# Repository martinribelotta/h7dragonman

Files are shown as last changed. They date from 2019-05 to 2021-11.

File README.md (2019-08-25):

# H7-DragonMAN board

STM32H7 LQFP100 board for protocol bridge and industrial control.

## Characterstics:

 - Isolated (see `isolated` branch) and non isolated version
 - STM32H750/743VxTx400MHz in 100LQFP with 8MHz/32.768Khz crystals and ROM Bootloader via USB
 - STM32-based DAP programmer and virtual usb with ROM bootloader via USB
 - External 2/4/8/16MB QSPI flash
 - MicroSD card 1bit slot
 - Two usb otg (FS and HS)
 - 10/100Mb ETH via KSZ8081 in RMII mode
 - RS485 isolated or non-isolated
 - CANBUS isolated or non-isolated
 - Isolated 3.3 to 5V step-up for CANBUS/RS-485 tranceivers
 - One user button
 - One user led
 - 5-24V input via AP63203 DC-DC regulator

## Schematic

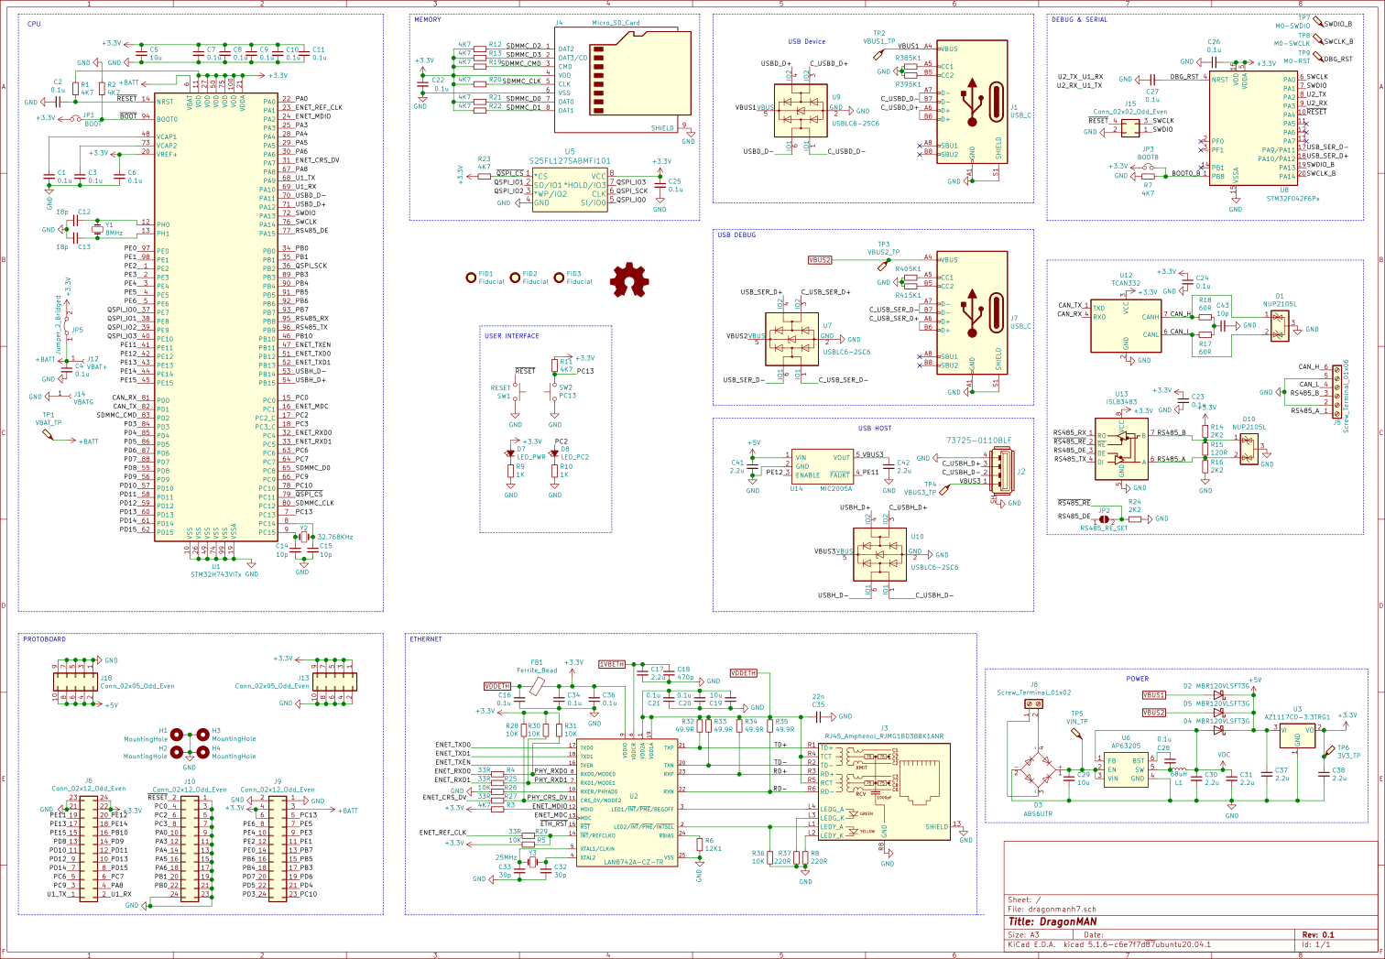
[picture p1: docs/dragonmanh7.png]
Schematic


## Board dimentions

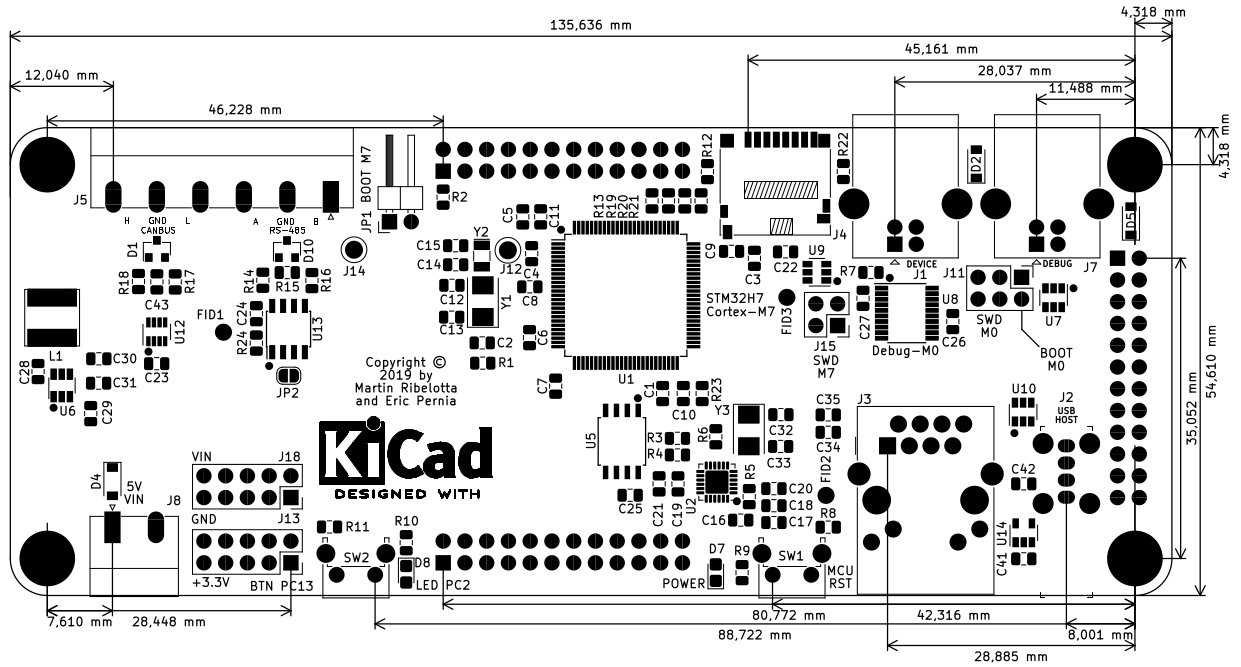
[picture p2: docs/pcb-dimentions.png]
Outline


## 3D preview

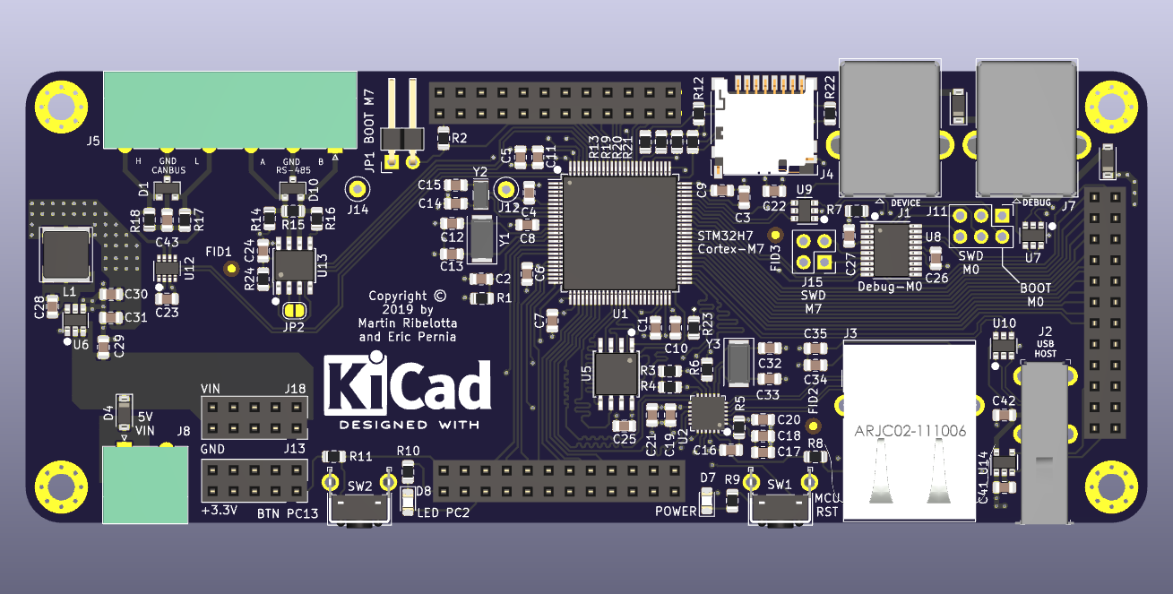
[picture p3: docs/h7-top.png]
top


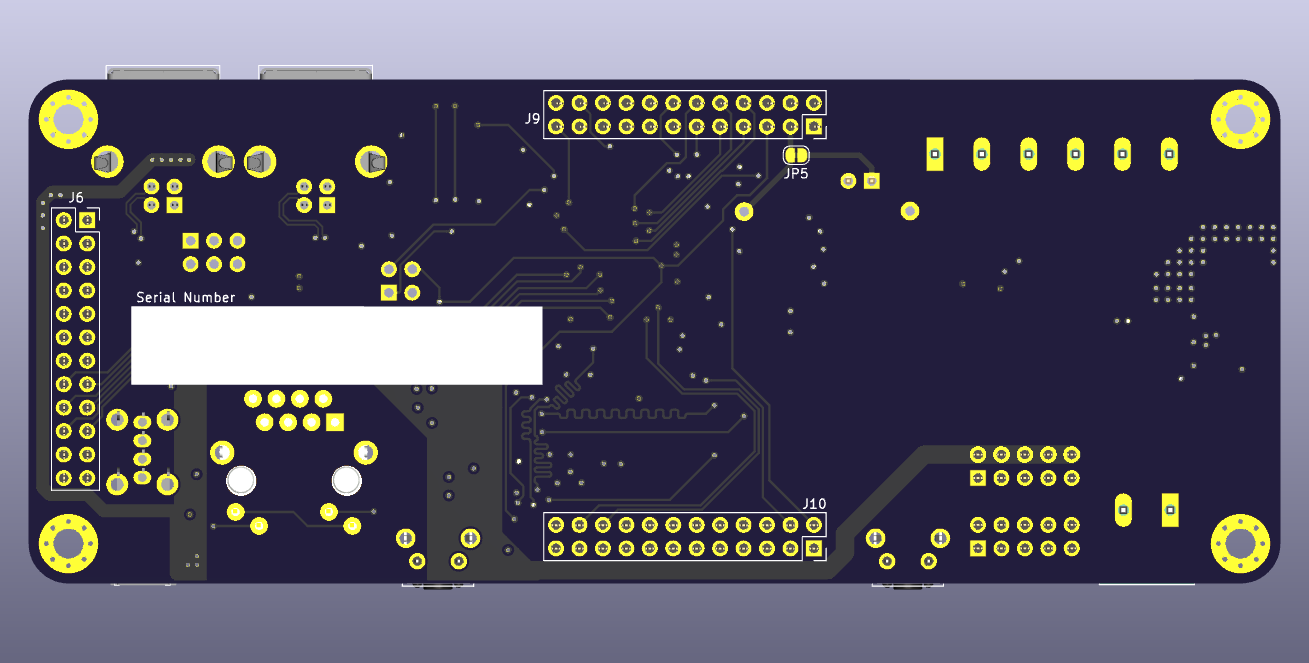
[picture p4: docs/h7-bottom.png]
bottom


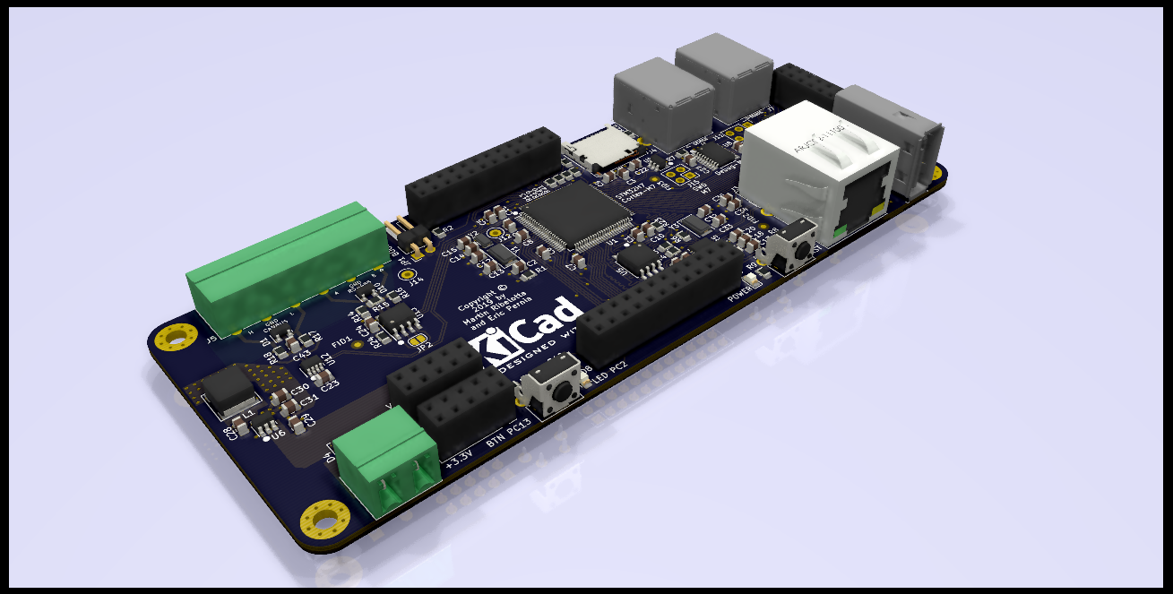
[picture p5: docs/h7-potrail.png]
potrail


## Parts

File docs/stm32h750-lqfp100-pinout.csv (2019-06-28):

Position | Name | Type | Signal | Label | AF0 | AF1 | AF2 | AF3 | AF4 | AF5 | AF6 | AF7 | AF8 | AF9 | AF10 | AF11 | AF12 | AF13 | AF14
1 | PE2 | I/O |  |  | SYS_TRACECLK |  | SAI1_CK1 |  |  | SPI4_SCK | SAI1_MCLK_A |  | SAI4_MCLK_A | QUADSPI_BK1_IO2 | SAI4_CK1 | ETH_TXD3 | FMC_A23
2 | PE3 | I/O |  |  | SYS_TRACED0 |  |  |  | TIM15_BKIN |  | SAI1_SD_B |  | SAI4_SD_B |  |  |  | FMC_A19
3 | PE4 | I/O |  |  | SYS_TRACED1 |  | SAI1_D2 | DFSDM1_DATIN3 | TIM15_CH1N | SPI4_NSS | SAI1_FS_A |  | SAI4_FS_A |  | SAI4_D2 |  | FMC_A20 | DCMI_D4 | LTDC_B0
4 | PE5 | I/O |  |  | SYS_TRACED2 |  | SAI1_CK2 | DFSDM1_CKIN3 | TIM15_CH1 | SPI4_MISO | SAI1_SCK_A |  | SAI4_SCK_A |  | SAI4_CK2 |  | FMC_A21 | DCMI_D6 | LTDC_G0
5 | PE6 | I/O |  |  | SYS_TRACED3 | TIM1_BKIN2 | SAI1_D1 |  | TIM15_CH2 | SPI4_MOSI | SAI1_SD_A |  | SAI4_SD_A | SAI4_D1 | SAI2_MCLK_B | TIM1_BKIN2_COMP1/TIM1_BKIN2_COMP2 | FMC_A22 | DCMI_D7 | LTDC_G1
6 | VBAT | Power
7 | PC13 | I/O
8 | PC14-OSC32_IN (OSC32_IN) | I/O
9 | PC15-OSC32_OUT (OSC32_OUT) | I/O
10 | VSS | Power
11 | VDD | Power
12 | PH0-OSC_IN (PH0) | I/O
13 | PH1-OSC_OUT (PH1) | I/O
14 | NRST | Reset
15 | PC0 | I/O |  |  |  |  |  | DFSDM1_CKIN0 |  |  | DFSDM1_DATIN4 |  | SAI2_FS_B |  | USB_OTG_HS_ULPI_STP |  | FMC_SDNWE |  | LTDC_R5
16 | PC1 | I/O |  |  | SYS_TRACED0 |  | SAI1_D1 | DFSDM1_DATIN0 | DFSDM1_CKIN4 | I2S2_SDO/SPI2_MOSI | SAI1_SD_A |  | SAI4_SD_A | SDMMC2_CK | SAI4_D1 | ETH_MDC | MDIOS_MDC
17 | PC2_C | I/O |  |  |  |  |  | DFSDM1_CKIN1 |  | I2S2_SDI/SPI2_MISO | DFSDM1_CKOUT |  |  |  | USB_OTG_HS_ULPI_DIR | ETH_TXD2 | FMC_SDNE0
18 | PC3_C | I/O |  |  |  |  |  | DFSDM1_DATIN1 |  | I2S2_SDO/SPI2_MOSI |  |  |  |  | USB_OTG_HS_ULPI_NXT | ETH_TX_CLK | FMC_SDCKE0
19 | VSSA | Power
20 | VREF+ | MonoIO
21 | VDDA | Power
22 | PA0 | I/O |  |  |  | TIM2_CH1/TIM2_ETR | TIM5_CH1 | TIM8_ETR | TIM15_BKIN |  |  | USART2_CTS/USART2_NSS | UART4_TX | SDMMC2_CMD | SAI2_SD_B | ETH_CRS
23 | PA1 | I/O |  |  |  | TIM2_CH2 | TIM5_CH2 | LPTIM3_OUT | TIM15_CH1N |  |  | USART2_DE/USART2_RTS | UART4_RX | QUADSPI_BK1_IO3 | SAI2_MCLK_B | ETH_REF_CLK/ETH_RX_CLK |  |  | LTDC_R2
24 | PA2 | I/O |  |  |  | TIM2_CH3 | TIM5_CH3 | LPTIM4_OUT | TIM15_CH1 |  |  | USART2_TX | SAI2_SCK_B |  |  | ETH_MDIO | MDIOS_MDIO |  | LTDC_R1
25 | PA3 | I/O |  |  |  | TIM2_CH4 | TIM5_CH4 | LPTIM5_OUT | TIM15_CH2 |  |  | USART2_RX |  | LTDC_B2 | USB_OTG_HS_ULPI_D0 | ETH_COL |  |  | LTDC_B5
26 | VSS | Power
27 | VDD | Power
28 | PA4 | I/O |  |  |  |  | TIM5_ETR |  |  | I2S1_WS/SPI1_NSS | I2S3_WS/SPI3_NSS | USART2_CK | SPI6_NSS |  |  |  | USB_OTG_HS_SOF | DCMI_HSYNC | LTDC_VSYNC
29 | PA5 | I/O |  |  |  | TIM2_CH1/TIM2_ETR |  | TIM8_CH1N |  | I2S1_CK/SPI1_SCK |  |  | SPI6_SCK |  | USB_OTG_HS_ULPI_CK |  |  |  | LTDC_R4
30 | PA6 | I/O |  |  |  | TIM1_BKIN | TIM3_CH1 | TIM8_BKIN |  | I2S1_SDI/SPI1_MISO |  |  | SPI6_MISO | TIM13_CH1 | TIM8_BKIN_COMP1/TIM8_BKIN_COMP2 | MDIOS_MDC | TIM1_BKIN_COMP1/TIM1_BKIN_COMP2 | DCMI_PIXCLK | LTDC_G2
31 | PA7 | I/O |  |  |  | TIM1_CH1N | TIM3_CH2 | TIM8_CH1N |  | I2S1_SDO/SPI1_MOSI |  |  | SPI6_MOSI | TIM14_CH1 |  | ETH_CRS_DV/ETH_RX_DV | FMC_SDNWE
32 | PC4 | I/O |  |  |  |  |  | DFSDM1_CKIN2 |  | I2S1_MCK |  |  |  | SPDIFRX1_IN2 |  | ETH_RXD0 | FMC_SDNE0
33 | PC5 | I/O |  |  |  |  | SAI1_D3 | DFSDM1_DATIN2 |  |  |  |  |  | SPDIFRX1_IN3 | SAI4_D3 | ETH_RXD1 | FMC_SDCKE0 | COMP1_OUT
34 | PB0 | I/O |  |  |  | TIM1_CH2N | TIM3_CH3 | TIM8_CH2N |  |  | DFSDM1_CKOUT |  | UART4_CTS | LTDC_R3 | USB_OTG_HS_ULPI_D1 | ETH_RXD2 |  |  | LTDC_G1
35 | PB1 | I/O |  |  |  | TIM1_CH3N | TIM3_CH4 | TIM8_CH3N |  |  | DFSDM1_DATIN1 |  |  | LTDC_R6 | USB_OTG_HS_ULPI_D2 | ETH_RXD3 |  |  | LTDC_G0
36 | PB2 | I/O |  |  | RTC_OUT_ALARM/RTC_OUT_CALIB |  | SAI1_D1 |  | DFSDM1_CKIN1 |  | SAI1_SD_A | I2S3_SDO/SPI3_MOSI | SAI4_SD_A | QUADSPI_CLK | SAI4_D1
37 | PE7 | I/O |  |  |  | TIM1_ETR |  | DFSDM1_DATIN2 |  |  |  | UART7_RX |  |  | QUADSPI_BK2_IO0 |  | FMC_D4/FMC_DA4
38 | PE8 | I/O |  |  |  | TIM1_CH1N |  | DFSDM1_CKIN2 |  |  |  | UART7_TX |  |  | QUADSPI_BK2_IO1 |  | FMC_D5/FMC_DA5 | COMP2_OUT
39 | PE9 | I/O |  |  |  | TIM1_CH1 |  | DFSDM1_CKOUT |  |  |  | UART7_DE/UART7_RTS |  |  | QUADSPI_BK2_IO2 |  | FMC_D6/FMC_DA6
40 | PE10 | I/O |  |  |  | TIM1_CH2N |  | DFSDM1_DATIN4 |  |  |  | UART7_CTS |  |  | QUADSPI_BK2_IO3 |  | FMC_D7/FMC_DA7
41 | PE11 | I/O |  |  |  | TIM1_CH2 |  | DFSDM1_CKIN4 |  | SPI4_NSS |  |  |  |  | SAI2_SD_B |  | FMC_D8/FMC_DA8 |  | LTDC_G3
42 | PE12 | I/O |  |  |  | TIM1_CH3N |  | DFSDM1_DATIN5 |  | SPI4_SCK |  |  |  |  | SAI2_SCK_B |  | FMC_D9/FMC_DA9 | COMP1_OUT | LTDC_B4
43 | PE13 | I/O |  |  |  | TIM1_CH3 |  | DFSDM1_CKIN5 |  | SPI4_MISO |  |  |  |  | SAI2_FS_B |  | FMC_D10/FMC_DA10 | COMP2_OUT | LTDC_DE
44 | PE14 | I/O |  |  |  | TIM1_CH4 |  |  |  | SPI4_MOSI |  |  |  |  | SAI2_MCLK_B |  | FMC_D11/FMC_DA11 |  | LTDC_CLK
45 | PE15 | I/O |  |  |  | TIM1_BKIN |  |  |  |  |  |  |  |  |  |  | FMC_D12/FMC_DA12 | TIM1_BKIN_COMP1/TIM1_BKIN_COMP2 | LTDC_R7
46 | PB10 | I/O |  |  |  | TIM2_CH3 | HRTIM_SCOUT | LPTIM2_IN1 | I2C2_SCL | I2S2_CK/SPI2_SCK | DFSDM1_DATIN7 | USART3_TX |  | QUADSPI_BK1_NCS | USB_OTG_HS_ULPI_D3 | ETH_RX_ER |  |  | LTDC_G4
47 | PB11 | I/O |  |  |  | TIM2_CH4 | HRTIM_SCIN | LPTIM2_ETR | I2C2_SDA |  | DFSDM1_CKIN7 | USART3_RX |  |  | USB_OTG_HS_ULPI_D4 | ETH_TX_EN |  |  | LTDC_G5
48 | VCAP | Power
49 | VSS | Power
50 | VDD | Power
51 | PB12 | I/O |  |  |  | TIM1_BKIN |  |  | I2C2_SMBA | I2S2_WS/SPI2_NSS | DFSDM1_DATIN1 | USART3_CK |  | FDCAN2_RX | USB_OTG_HS_ULPI_D5 | ETH_TXD0 | USB_OTG_HS_ID | TIM1_BKIN_COMP1/TIM1_BKIN_COMP2 | UART5_RX
52 | PB13 | I/O |  |  |  | TIM1_CH1N |  | LPTIM2_OUT |  | I2S2_CK/SPI2_SCK | DFSDM1_CKIN1 | USART3_CTS/USART3_NSS |  | FDCAN2_TX | USB_OTG_HS_ULPI_D6 | ETH_TXD1 |  |  | UART5_TX
53 | PB14 | I/O |  |  |  | TIM1_CH2N | TIM12_CH1 | TIM8_CH2N | USART1_TX | I2S2_SDI/SPI2_MISO | DFSDM1_DATIN2 | USART3_DE/USART3_RTS | UART4_DE/UART4_RTS | SDMMC2_D0 |  |  | USB_OTG_HS_DM
54 | PB15 | I/O |  |  | RTC_REFIN | TIM1_CH3N | TIM12_CH2 | TIM8_CH3N | USART1_RX | I2S2_SDO/SPI2_MOSI | DFSDM1_CKIN2 |  | UART4_CTS | SDMMC2_D1 |  |  | USB_OTG_HS_DP
55 | PD8 | I/O |  |  |  |  |  | DFSDM1_CKIN3 |  |  | SAI3_SCK_B | USART3_TX |  | SPDIFRX1_IN1 |  |  | FMC_D13/FMC_DA13
56 | PD9 | I/O |  |  |  |  |  | DFSDM1_DATIN3 |  |  | SAI3_SD_B | USART3_RX |  |  |  |  | FMC_D14/FMC_DA14
57 | PD10 | I/O |  |  |  |  |  | DFSDM1_CKOUT |  |  | SAI3_FS_B | USART3_CK |  |  |  |  | FMC_D15/FMC_DA15 |  | LTDC_B3
58 | PD11 | I/O |  |  |  |  |  | LPTIM2_IN2 | I2C4_SMBA |  |  | USART3_CTS/USART3_NSS |  | QUADSPI_BK1_IO0 | SAI2_SD_A |  | FMC_A16
59 | PD12 | I/O |  |  |  | LPTIM1_IN1 | TIM4_CH1 | LPTIM2_IN1 | I2C4_SCL |  |  | USART3_DE/USART3_RTS |  | QUADSPI_BK1_IO1 | SAI2_FS_A |  | FMC_A17
60 | PD13 | I/O |  |  |  | LPTIM1_OUT | TIM4_CH2 |  | I2C4_SDA |  |  |  |  | QUADSPI_BK1_IO3 | SAI2_SCK_A |  | FMC_A18
61 | PD14 | I/O |  |  |  |  | TIM4_CH3 |  |  |  | SAI3_MCLK_B |  | UART8_CTS |  |  |  | FMC_D0/FMC_DA0
62 | PD15 | I/O |  |  |  |  | TIM4_CH4 |  |  |  | SAI3_MCLK_A |  | UART8_DE/UART8_RTS |  |  |  | FMC_D1/FMC_DA1
63 | PC6 | I/O |  |  |  | HRTIM_CHA1 | TIM3_CH1 | TIM8_CH1 | DFSDM1_CKIN3 | I2S2_MCK |  | USART6_TX | SDMMC1_D0DIR | FMC_NWAIT | SDMMC2_D6 |  | SDMMC1_D6 | DCMI_D0 | LTDC_HSYNC
64 | PC7 | I/O |  |  | SYS_TRGIO | HRTIM_CHA2 | TIM3_CH2 | TIM8_CH2 | DFSDM1_DATIN3 |  | I2S3_MCK | USART6_RX | SDMMC1_D123DIR | FMC_NE1 | SDMMC2_D7 | SWPMI1_TX | SDMMC1_D7 | DCMI_D1 | LTDC_G6
65 | PC8 | I/O |  |  | SYS_TRACED1 | HRTIM_CHB1 | TIM3_CH3 | TIM8_CH3 |  |  |  | USART6_CK | UART5_DE/UART5_RTS | FMC_NCE/FMC_NE2 |  | SWPMI1_RX | SDMMC1_D0 | DCMI_D2
66 | PC9 | I/O |  |  | RCC_MCO_2 |  | TIM3_CH4 | TIM8_CH4 | I2C3_SDA | I2S_CKIN |  |  | UART5_CTS | QUADSPI_BK1_IO0 | LTDC_G3 | SWPMI1_SUSPEND | SDMMC1_D1 | DCMI_D3 | LTDC_B2
67 | PA8 | I/O |  |  | RCC_MCO_1 | TIM1_CH1 | HRTIM_CHB2 | TIM8_BKIN2 | I2C3_SCL |  |  | USART1_CK |  |  | USB_OTG_FS_SOF | UART7_RX | TIM8_BKIN2_COMP1/TIM8_BKIN2_COMP2 | LTDC_B3 | LTDC_R6
68 | PA9 | I/O |  |  |  | TIM1_CH2 | HRTIM_CHC1 | LPUART1_TX | I2C3_SMBA | I2S2_CK/SPI2_SCK |  | USART1_TX |  |  |  |  |  | DCMI_D0 | LTDC_R5
69 | PA10 | I/O |  |  |  | TIM1_CH3 | HRTIM_CHC2 | LPUART1_RX |  |  |  | USART1_RX |  |  | USB_OTG_FS_ID | MDIOS_MDIO | LTDC_B4 | DCMI_D1 | LTDC_B1
70 | PA11 | I/O |  |  |  | TIM1_CH4 | HRTIM_CHD1 | LPUART1_CTS |  | I2S2_WS/SPI2_NSS | UART4_RX | USART1_CTS/USART1_NSS |  | FDCAN1_RX | USB_OTG_FS_DM |  |  |  | LTDC_R4
71 | PA12 | I/O |  |  |  | TIM1_ETR | HRTIM_CHD2 | LPUART1_DE/LPUART1_RTS |  | I2S2_CK/SPI2_SCK | UART4_TX | USART1_DE/USART1_RTS | SAI2_FS_B | FDCAN1_TX | USB_OTG_FS_DP |  |  |  | LTDC_R5
72 | PA13 (JTMS/SWDIO) | I/O |  |  | SYS_JTMS-SWDIO
73 | VCAP | Power
74 | VSS | Power
75 | VDD | Power
76 | PA14 (JTCK/SWCLK) | I/O |  |  | SYS_JTCK-SWCLK
77 | PA15 (JTDI) | I/O |  |  | SYS_JTDI | TIM2_CH1/TIM2_ETR | HRTIM_FLT1 |  | CEC | I2S1_WS/SPI1_NSS | I2S3_WS/SPI3_NSS | SPI6_NSS | UART4_DE/UART4_RTS |  |  | UART7_TX
78 | PC10 | I/O |  |  |  |  | HRTIM_EEV1 | DFSDM1_CKIN5 |  |  | I2S3_CK/SPI3_SCK | USART3_TX | UART4_TX | QUADSPI_BK1_IO1 |  |  | SDMMC1_D2 | DCMI_D8 | LTDC_R2
79 | PC11 | I/O |  |  |  |  | HRTIM_FLT2 | DFSDM1_DATIN5 |  |  | I2S3_SDI/SPI3_MISO | USART3_RX | UART4_RX | QUADSPI_BK2_NCS |  |  | SDMMC1_D3 | DCMI_D4
80 | PC12 | I/O |  |  | SYS_TRACED3 |  | HRTIM_EEV2 |  |  |  | I2S3_SDO/SPI3_MOSI | USART3_CK | UART5_TX |  |  |  | SDMMC1_CK | DCMI_D9
81 | PD0 | I/O |  |  |  |  |  | DFSDM1_CKIN6 |  |  | SAI3_SCK_A |  | UART4_RX | FDCAN1_RX |  |  | FMC_D2/FMC_DA2
82 | PD1 | I/O |  |  |  |  |  | DFSDM1_DATIN6 |  |  | SAI3_SD_A |  | UART4_TX | FDCAN1_TX |  |  | FMC_D3/FMC_DA3
83 | PD2 | I/O |  |  | SYS_TRACED2 |  | TIM3_ETR |  |  |  |  |  | UART5_RX |  |  |  | SDMMC1_CMD | DCMI_D11
84 | PD3 | I/O |  |  |  |  |  | DFSDM1_CKOUT |  | I2S2_CK/SPI2_SCK |  | USART2_CTS/USART2_NSS |  |  |  |  | FMC_CLK | DCMI_D5 | LTDC_G7
85 | PD4 | I/O |  |  |  |  | HRTIM_FLT3 |  |  |  | SAI3_FS_A | USART2_DE/USART2_RTS |  |  |  |  | FMC_NOE
86 | PD5 | I/O |  |  |  |  | HRTIM_EEV3 |  |  |  |  | USART2_TX |  |  |  |  | FMC_NWE
87 | PD6 | I/O |  |  |  |  | SAI1_D1 | DFSDM1_CKIN4 | DFSDM1_DATIN1 | I2S3_SDO/SPI3_MOSI | SAI1_SD_A | USART2_RX | SAI4_SD_A |  | SAI4_D1 | SDMMC2_CK | FMC_NWAIT | DCMI_D10 | LTDC_B2
88 | PD7 | I/O |  |  |  |  |  | DFSDM1_DATIN4 |  | I2S1_SDO/SPI1_MOSI | DFSDM1_CKIN1 | USART2_CK |  | SPDIFRX1_IN0 |  | SDMMC2_CMD | FMC_NE1
89 | PB3 (JTDO/TRACESWO) | I/O |  |  | SYS_JTDO-SWO | TIM2_CH2 | HRTIM_FLT4 |  |  | I2S1_CK/SPI1_SCK | I2S3_CK/SPI3_SCK |  | SPI6_SCK | SDMMC2_D2 | CRS_SYNC | UART7_RX
90 | PB4 (NJTRST) | I/O |  |  | SYS_JTRST | TIM16_BKIN | TIM3_CH1 | HRTIM_EEV6 |  | I2S1_SDI/SPI1_MISO | I2S3_SDI/SPI3_MISO | I2S2_WS/SPI2_NSS | SPI6_MISO | SDMMC2_D3 |  | UART7_TX
91 | PB5 | I/O |  |  |  | TIM17_BKIN | TIM3_CH2 | HRTIM_EEV7 | I2C1_SMBA | I2S1_SDO/SPI1_MOSI | I2C4_SMBA | I2S3_SDO/SPI3_MOSI | SPI6_MOSI | FDCAN2_RX | USB_OTG_HS_ULPI_D7 | ETH_PPS_OUT | FMC_SDCKE1 | DCMI_D10 | UART5_RX
92 | PB6 | I/O |  |  |  | TIM16_CH1N | TIM4_CH1 | HRTIM_EEV8 | I2C1_SCL | CEC | I2C4_SCL | USART1_TX | LPUART1_TX | FDCAN2_TX | QUADSPI_BK1_NCS | DFSDM1_DATIN5 | FMC_SDNE1 | DCMI_D5 | UART5_TX
93 | PB7 | I/O |  |  |  | TIM17_CH1N | TIM4_CH2 | HRTIM_EEV9 | I2C1_SDA |  | I2C4_SDA | USART1_RX | LPUART1_RX |  |  | DFSDM1_CKIN5 | FMC_NL | DCMI_VSYNC
94 | BOOT0 | Boot
95 | PB8 | I/O |  |  |  | TIM16_CH1 | TIM4_CH3 | DFSDM1_CKIN7 | I2C1_SCL |  | I2C4_SCL | SDMMC1_CKIN | UART4_RX | FDCAN1_RX | SDMMC2_D4 | ETH_TXD3 | SDMMC1_D4 | DCMI_D6 | LTDC_B6
96 | PB9 | I/O |  |  |  | TIM17_CH1 | TIM4_CH4 | DFSDM1_DATIN7 | I2C1_SDA | I2S2_WS/SPI2_NSS | I2C4_SDA | SDMMC1_CDIR | UART4_TX | FDCAN1_TX | SDMMC2_D5 | I2C4_SMBA | SDMMC1_D5 | DCMI_D7 | LTDC_B7
97 | PE0 | I/O |  |  |  | LPTIM1_ETR | TIM4_ETR | HRTIM_SCIN | LPTIM2_ETR |  |  |  | UART8_RX |  | SAI2_MCLK_A |  | FMC_NBL0 | DCMI_D2
98 | PE1 | I/O |  |  |  | LPTIM1_IN2 |  | HRTIM_SCOUT |  |  |  |  | UART8_TX |  |  |  | FMC_NBL1 | DCMI_D3
99 | VSS | Power
100 | VDD | Power

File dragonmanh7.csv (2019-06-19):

Source: | /home/martin/Proyectos/kicad/trololo/trololo/trololo.sch
Date: | mié 08 may 2019 14:37:29 -03
Tool: | Eeschema 5.1.2-f72e74a~84~ubuntu18.04.1
Generator: | /usr/share/kicad/plugins/bom_csv_grouped_by_value.py
Component Count: | 103
Individual Components:
Item | Qty | Reference(s) | Value | LibPart | Footprint | Datasheet | Category | DK_Datasheet_Link | DK_Detail_Page | Description | Digi-Key_PN | Family | MPN | Manufacturer | Status | manf#
 |  | C1 | 0.1u | Device:C_Small | Capacitor_SMD:C_0805_2012Metric | ~ |  |  |  |  |  |  |  |  |  | 885012207098
 |  | C2 | 0.1u | Device:C_Small | Capacitor_SMD:C_0805_2012Metric | ~ |  |  |  |  |  |  |  |  |  | 885012207098
 |  | C3 | 0.1u | Device:C_Small | Capacitor_SMD:C_0805_2012Metric | ~ |  |  |  |  |  |  |  |  |  | 885012207098
 |  | C4 | 0.1u | Device:C_Small | Capacitor_SMD:C_0805_2012Metric | ~ |  |  |  |  |  |  |  |  |  | 885012207098
 |  | C5 | 4.7u | Device:C_Small | Capacitor_SMD:C_0805_2012Metric | ~ |  |  |  |  |  |  |  |  |  | LMK212B7475MG-T
 |  | C6 | 0.1u | Device:C_Small | Capacitor_SMD:C_0805_2012Metric | ~ |  |  |  |  |  |  |  |  |  | 885012207098
 |  | C7 | 0.1u | Device:C_Small | Capacitor_SMD:C_0805_2012Metric | ~ |  |  |  |  |  |  |  |  |  | 885012207098
 |  | C8 | 0.1u | Device:C_Small | Capacitor_SMD:C_0805_2012Metric | ~ |  |  |  |  |  |  |  |  |  | 885012207098
 |  | C9 | 0.1u | Device:C_Small | Capacitor_SMD:C_0805_2012Metric | ~ |  |  |  |  |  |  |  |  |  | 885012207098
 |  | C10 | 0.1u | Device:C_Small | Capacitor_SMD:C_0805_2012Metric | ~ |  |  |  |  |  |  |  |  |  | 885012207098
 |  | C11 | 0.1u | Device:C_Small | Capacitor_SMD:C_0805_2012Metric | ~ |  |  |  |  |  |  |  |  |  | 885012207098
 |  | C12 | 18p | Device:C_Small | Capacitor_SMD:C_0805_2012Metric | ~ |  |  |  |  |  |  |  |  |  | CL21C180JBANNNC
 |  | C13 | 18p | Device:C_Small | Capacitor_SMD:C_0805_2012Metric | ~ |  |  |  |  |  |  |  |  |  | CL21C180JBANNNC
 |  | C14 | 10p | Device:C_Small | Capacitor_SMD:C_0805_2012Metric | ~ |  |  |  |  |  |  |  |  |  | 885012007010
 |  | C15 | 10p | Device:C_Small | Capacitor_SMD:C_0805_2012Metric | ~ |  |  |  |  |  |  |  |  |  | 885012007010
 |  | C16 | 0.1u | Device:C_Small | Capacitor_SMD:C_0805_2012Metric | ~ |  |  |  |  |  |  |  |  |  | 885012207098
 |  | C17 | 2.2u | Device:C_Small | Capacitor_SMD:C_0805_2012Metric | ~ |  |  |  |  |  |  |  |  |  | CL31B225KOHNNNE
 |  | C18 | 4.7u | Device:C_Small | Capacitor_SMD:C_0805_2012Metric | ~ |  |  |  |  |  |  |  |  |  | LMK212B7475MG-T
 |  | C19 | 4.7u | Device:C_Small | Capacitor_SMD:C_0805_2012Metric | ~ |  |  |  |  |  |  |  |  |  | LMK212B7475MG-T
 |  | C20 | 0.1u | Device:C_Small | Capacitor_SMD:C_0805_2012Metric | ~ |  |  |  |  |  |  |  |  |  | 885012207098
 |  | C21 | 0.1u | Device:C_Small | Capacitor_SMD:C_0805_2012Metric | ~ |  |  |  |  |  |  |  |  |  | 885012207098
 |  | C22 | 0.1u | Device:C_Small | Capacitor_SMD:C_0805_2012Metric | ~ |  |  |  |  |  |  |  |  |  | 885012207098
 |  | C23 | 0.1u | Device:C_Small | Capacitor_SMD:C_0805_2012Metric | ~ |  |  |  |  |  |  |  |  |  | 885012207098
 |  | C24 | 0.1u | Device:C_Small | Capacitor_SMD:C_0805_2012Metric | ~ |  |  |  |  |  |  |  |  |  | 885012207098
 |  | C25 | 0.1u | Device:C_Small | Capacitor_SMD:C_0805_2012Metric | ~ |  |  |  |  |  |  |  |  |  | 885012207098
 |  | C26 | 0.1u | Device:C_Small | Capacitor_SMD:C_0805_2012Metric | ~ |  |  |  |  |  |  |  |  |  | 885012207098
 |  | C27 | 0.1u | Device:C_Small | Capacitor_SMD:C_0805_2012Metric | ~ |  |  |  |  |  |  |  |  |  | 885012207098
 |  | C28 | 0.1u | Device:C_Small | Capacitor_SMD:C_0805_2012Metric | ~ |  |  |  |  |  |  |  |  |  | 885012207098
 |  | C29 | 10u | Device:C_Small | Capacitor_SMD:C_0805_2012Metric | ~ |  |  |  |  |  |  |  |  |  | CL21A106MQFNNNE
 |  | C30 | 2.2u | Device:C_Small | Capacitor_SMD:C_0805_2012Metric | ~ |  |  |  |  |  |  |  |  |  | CL31B225KOHNNNE
 |  | C31 | 2.2u | Device:C_Small | Capacitor_SMD:C_0805_2012Metric | ~ |  |  |  |  |  |  |  |  |  | CL31B225KOHNNNE
 |  | C32 | 22p | Device:C_Small | Capacitor_SMD:C_0805_2012Metric | ~ |  |  |  |  |  |  |  |  |  | 885012007012
 |  | C33 | 22p | Device:C_Small | Capacitor_SMD:C_0805_2012Metric | ~ |  |  |  |  |  |  |  |  |  | 885012007012
 |  | C34 | 0.1u | Device:C_Small | Capacitor_SMD:C_0805_2012Metric | ~ |  |  |  |  |  |  |  |  |  | 885012207098
 |  | C35 | 0.1u | Device:C_Small | Capacitor_SMD:C_0805_2012Metric | ~ |  |  |  |  |  |  |  |  |  | 885012207098
 |  | C36 | 0.1u | Device:C_Small | Capacitor_SMD:C_0805_2012Metric | ~ |  |  |  |  |  |  |  |  |  | 885012207098
 |  | C37 | 0.1u | Device:C_Small | Capacitor_SMD:C_0805_2012Metric | ~ |  |  |  |  |  |  |  |  |  | 885012207098
 |  | C38 | 0.1u | Device:C_Small | Capacitor_SMD:C_0805_2012Metric | ~ |  |  |  |  |  |  |  |  |  | 885012207098
 |  | C39 | 10u | Device:C_Small | Capacitor_SMD:C_0805_2012Metric | ~ |  |  |  |  |  |  |  |  |  | CL21A106MQFNNNE
 |  | C40 | 0.1u | Device:C_Small | Capacitor_SMD:C_0805_2012Metric | ~ |  |  |  |  |  |  |  |  |  | 885012207098
 |  | D1 | NUP2105L | Power_Protection:NUP2105L | Package_TO_SOT_SMD:SOT-23 | http://www.onsemi.com/pub_link/Collateral/NUP2105L-D.PDF |  |  |  |  |  |  |  |  |  | NUP2105L
 |  | D2 | B120-E3 | Diode:B120-E3 | Diode_SMD:D_SMA | http://www.vishay.com/docs/88946/b120.pdf |  |  |  |  |  |  |  |  |  | B120-E3
 |  | D4 | B120-E3 | Diode:B120-E3 | Diode_SMD:D_SMA | http://www.vishay.com/docs/88946/b120.pdf |  |  |  |  |  |  |  |  |  | B120-E3
 |  | D5 | B120-E3 | Diode:B120-E3 | Diode_SMD:D_SMA | http://www.vishay.com/docs/88946/b120.pdf |  |  |  |  |  |  |  |  |  | B120-E3
 |  | D6 | B120-E3 | Diode:B120-E3 | Diode_SMD:D_SMA | http://www.vishay.com/docs/88946/b120.pdf |  |  |  |  |  |  |  |  |  | B120-E3
 |  | D7 | LED_PWR | Device:LED_Small_ALT | LED_SMD:LED_0805_2012Metric_Castellated | ~ |  |  |  |  |  |  |  |  |  | 150080RS75000
 |  | D8 | LED_PA8 | Device:LED_Small_ALT | LED_SMD:LED_0805_2012Metric_Castellated | ~ |  |  |  |  |  |  |  |  |  | 150080RS75000
 |  | D10 | NUP2105L | Power_Protection:NUP2105L | Package_TO_SOT_SMD:SOT-23 | http://www.onsemi.com/pub_link/Collateral/NUP2105L-D.PDF |  |  |  |  |  |  |  |  |  | NUP2105L
 |  | D11 | B120-E3 | Diode:B120-E3 | Diode_SMD:D_SMA | http://www.vishay.com/docs/88946/b120.pdf |  |  |  |  |  |  |  |  |  | B120-E3
 |  | D12 | B120-E3 | Diode:B120-E3 | Diode_SMD:D_SMA | http://www.vishay.com/docs/88946/b120.pdf |  |  |  |  |  |  |  |  |  | B120-E3
 |  | H1 | MountingHole | Mechanical:MountingHole_Pad | MountingHole:MountingHole_3.2mm_M3_Pad_Via | ~
 |  | H2 | MountingHole | Mechanical:MountingHole_Pad | MountingHole:MountingHole_3.2mm_M3_Pad_Via | ~
 |  | H3 | MountingHole | Mechanical:MountingHole_Pad | MountingHole:MountingHole_3.2mm_M3_Pad_Via | ~
 |  | H4 | MountingHole | Mechanical:MountingHole_Pad | MountingHole:MountingHole_3.2mm_M3_Pad_Via | ~
 |  | J1 | 10118194-0001LF | dk_USB-DVI-HDMI-Connectors:10118194-0001LF | footprints:USB_Micro_B_Female_10118194-0001LF | http://www.amphenol-icc.com/media/wysiwyg/files/drawing/10118194.pdf | Connectors, Interconnects | http://www.amphenol-icc.com/media/wysiwyg/files/drawing/10118194.pdf | /product-detail/en/amphenol-icc-fci/10118194-0001LF/609-4618-1-ND/2785382 | CONN RCPT USB2.0 MICRO B SMD R/A | 609-4618-1-ND | USB, DVI, HDMI Connectors | 10118194-0001LF | Amphenol ICC (FCI) | Active | 10118194-0001LF
 |  | J2 | 10118194-0001LF | dk_USB-DVI-HDMI-Connectors:10118194-0001LF | footprints:USB_Micro_B_Female_10118194-0001LF | http://www.amphenol-icc.com/media/wysiwyg/files/drawing/10118194.pdf | Connectors, Interconnects | http://www.amphenol-icc.com/media/wysiwyg/files/drawing/10118194.pdf | /product-detail/en/amphenol-icc-fci/10118194-0001LF/609-4618-1-ND/2785382 | CONN RCPT USB2.0 MICRO B SMD R/A | 609-4618-1-ND | USB, DVI, HDMI Connectors | 10118194-0001LF | Amphenol ICC (FCI) | Active | 10118194-0001LF
 |  | J3 | RJ45_Amphenol_RJMG1BD3B8K1ANR | Connector:RJ45_Amphenol_RJMG1BD3B8K1ANR | Connector_RJ:RJ45_Amphenol_RJMG1BD3B8K1ANR | https://www.amphenolcanada.com/ProductSearch/Drawings/AC/RJMG1BD3B8K1ANR.PDF |  |  |  |  |  |  |  |  |  | RJMG1BD3B8K1ANR
 |  | J4 | Micro_SD_Card | trololo-rescue:Micro_SD_Card-Connector | Connector_Card:microSD_HC_Hirose_DM3D-SF | http://katalog.we-online.de/em/datasheet/693072010801.pdf |  |  |  |  |  |  |  |  |  | DM3D-SF
 |  | J5 | Screw_Terminal_01x06 | Connector:Screw_Terminal_01x06 | Connector_Phoenix_MC:PhoenixContact_MC_1,5_6-GF-3.5_1x06_P3.50mm_Horizontal_ThreadedFlange_MountHole | ~ |  |  |  |  |  |  |  |  |  | 1985234
 |  | J6 | Conn_02x12_Odd_Even | Connector_Generic:Conn_02x12_Odd_Even | Connector_PinSocket_2.54mm:PinSocket_2x12_P2.54mm_Vertical | ~
 |  | J7 | 10118194-0001LF | dk_USB-DVI-HDMI-Connectors:10118194-0001LF | footprints:USB_Micro_B_Female_10118194-0001LF | http://www.amphenol-icc.com/media/wysiwyg/files/drawing/10118194.pdf | Connectors, Interconnects | http://www.amphenol-icc.com/media/wysiwyg/files/drawing/10118194.pdf | /product-detail/en/amphenol-icc-fci/10118194-0001LF/609-4618-1-ND/2785382 | CONN RCPT USB2.0 MICRO B SMD R/A | 609-4618-1-ND | USB, DVI, HDMI Connectors | 10118194-0001LF | Amphenol ICC (FCI) | Active | 10118194-0001LF
 |  | J8 | Screw_Terminal_01x02 | Connector:Screw_Terminal_01x02 | Connector_Phoenix_MC:PhoenixContact_MC_1,5_2-GF-3.5_1x02_P3.50mm_Horizontal_ThreadedFlange_MountHole | ~ |  |  |  |  |  |  |  |  |  | 1985195
 |  | J9 | Conn_02x12_Odd_Even | Connector_Generic:Conn_02x12_Odd_Even | Connector_PinSocket_2.54mm:PinSocket_2x12_P2.54mm_Vertical | ~
 |  | J10 | Conn_02x12_Odd_Even | Connector_Generic:Conn_02x12_Odd_Even | Connector_PinSocket_2.54mm:PinSocket_2x12_P2.54mm_Vertical | ~
 |  | J11 | Conn_02x02_Odd_Even | Connector_Generic:Conn_02x02_Odd_Even | Connector_PinHeader_2.54mm:PinHeader_2x02_P2.54mm_Vertical | ~
 |  | J13 | PROTO1 | Connector_Generic:Conn_02x10_Odd_Even | Connector_PinHeader_2.54mm:PinHeader_2x10_P2.54mm_Vertical | ~
 |  | J18 | PROTO1 | Connector_Generic:Conn_02x10_Odd_Even | Connector_PinHeader_2.54mm:PinHeader_2x10_P2.54mm_Vertical | ~
 |  | JP1 | BOOT | Device:Jumper_NC_Small | Connector_PinHeader_2.54mm:PinHeader_1x02_P2.54mm_Horizontal | ~
 |  | JP2 | Jumper_2_Bridged | Jumper:Jumper_2_Bridged | Jumper:SolderJumper-2_P1.3mm_Bridged_RoundedPad1.0x1.5mm | ~
 |  | JP3 | Jumper_2_Bridged | Jumper:Jumper_2_Bridged | Jumper:SolderJumper-2_P1.3mm_Bridged_RoundedPad1.0x1.5mm | ~
 |  | JP4 | Jumper_2_Bridged | Jumper:Jumper_2_Bridged | Jumper:SolderJumper-2_P1.3mm_Open_RoundedPad1.0x1.5mm | ~
 |  | JP5 | Jumper_2_Bridged | Jumper:Jumper_2_Bridged | Jumper:SolderJumper-2_P1.3mm_Open_RoundedPad1.0x1.5mm | ~
 |  | L1 | 68uH | Device:L_Small | Inductor_SMD:L_6.3x6.3_H3 | ~ |  |  |  |  |  |  |  |  |  | 1255AY-3R9N=P3
 |  | R1 | 4K7 | Device:R_Small | Resistor_SMD:R_0805_2012Metric | ~ |  |  |  |  |  |  |  |  |  | RC0805JR-074K7L
 |  | R2 | 4K7 | Device:R_Small | Resistor_SMD:R_0805_2012Metric | ~ |  |  |  |  |  |  |  |  |  | RC0805JR-074K7L
 |  | R3 | 4K7 | Device:R_Small | Resistor_SMD:R_0805_2012Metric | ~ |  |  |  |  |  |  |  |  |  | RC0805JR-074K7L
 |  | R4 | 4K7 | Device:R_Small | Resistor_SMD:R_0805_2012Metric | ~ |  |  |  |  |  |  |  |  |  | RC0805JR-074K7L
 |  | R5 | 4K7 | Device:R_Small | Resistor_SMD:R_0805_2012Metric | ~ |  |  |  |  |  |  |  |  |  | RC0805JR-074K7L
 |  | R6 | 6.49K 1% | Device:R_Small | Resistor_SMD:R_0805_2012Metric | ~ |  |  |  |  |  |  |  |  |  | RMCF0805FT6K49
 |  | R7 | 4K7 | Device:R_Small | Resistor_SMD:R_0805_2012Metric | ~ |  |  |  |  |  |  |  |  |  | RC0805JR-074K7L
 |  | R8 | 220R | Device:R_Small | Resistor_SMD:R_0805_2012Metric | ~ |  |  |  |  |  |  |  |  |  | CRGCQ0805J22R
 |  | R9 | 220R | Device:R_Small | Resistor_SMD:R_0805_2012Metric | ~ |  |  |  |  |  |  |  |  |  | CRGCQ0805J22R
 |  | R10 | 220R | Device:R_Small | Resistor_SMD:R_0805_2012Metric | ~ |  |  |  |  |  |  |  |  |  | CRGCQ0805J22R
 |  | R11 | 4K7 | Device:R_Small | Resistor_SMD:R_0805_2012Metric | ~ |  |  |  |  |  |  |  |  |  | RC0805JR-074K7L
 |  | SW1 | RESET | Switch:SW_Push | Button_Switch_SMD:SW_SPST_TL3342 | ~ |  |  |  |  |  |  |  |  |  | TL3342
 |  | SW2 | PC13 | Switch:SW_Push | Button_Switch_THT:SW_Tactile_SPST_Angled_PTS645Vx31-2LFS | ~ |  |  |  |  |  |  |  |  |  | PTS645VM31-2 LFS
 |  | TR1 | ADTT1-6 | Transformer:ADTT1-6 | Transformer_SMD:Pulse_P0926NL | https://ww2.minicircuits.com/pdfs/ADTT1-6+.pdf |  |  |  |  |  |  |  |  |  | 750315371
 |  | U1 | STM32H743VITx | MCU_ST_STM32H7:STM32H743VITx | Package_QFP:LQFP-100_14x14mm_P0.5mm | http://www.st.com/st-web-ui/static/active/en/resource/technical/document/datasheet/DM00387108.pdf |  |  |  |  |  |  |  |  |  | STM32H743VIT6
 |  | U2 | KSZ8081RNA | Interface_Ethernet:KSZ8081RNA | Package_DFN_QFN:QFN-24-1EP_4x4mm_P0.5mm_EP2.6x2.6mm | http://ww1.microchip.com/downloads/en/DeviceDoc/00002199A.pdf |  |  |  |  |  |  |  |  |  | KSZ8081RNA
 |  | U3 | ISO1050DUB | trololo-rescue:ISO1050DUB-Interface_CAN_LIN | Package_SO:SOP-8_6.62x9.15mm_P2.54mm | http://www.ti.com/lit/ds/symlink/iso1050.pdf |  |  |  |  |  |  |  |  |  | ISO1050DUB
 |  | U4 | ISO3082DW | Interface_UART:ISO3082DW | Package_SO:SOIC-16W_7.5x10.3mm_P1.27mm | http://www.ti.com/lit/ds/symlink/iso3082.pdf |  |  |  |  |  |  |  |  |  | ISO3082DW
 |  | U5 | S25FL127SABMFI101 | 2019-03-05_02-01-41:S25FL127SABMFI101 | footprints:S25FL127SABMFI101 |  |  |  |  |  |  |  |  |  |  | S25FL127SABMFI101
 |  | U6 | AP63203 | reg_ap6320x:AP63203 | Package_TO_SOT_SMD:TSOT-23-6 |  |  |  |  |  |  |  |  |  |  | AP63203WU-7
 |  | U7 | USBLC6-2SC6 | Power_Protection:USBLC6-2SC6 | Package_TO_SOT_SMD:SOT-23-6 | http://www2.st.com/resource/en/datasheet/CD00050750.pdf |  |  |  |  |  |  |  |  |  | USBLC6-2SC6
 |  | U8 | STM32F042F6Px | MCU_ST_STM32F0:STM32F042F4Px | Package_SO:TSSOP-20_4.4x6.5mm_P0.65mm | http://www.st.com/st-web-ui/static/active/en/resource/technical/document/datasheet/DM00105814.pdf |  |  |  |  |  |  |  |  |  | STM32F042F6P6
 |  | U9 | USBLC6-2SC6 | Power_Protection:USBLC6-2SC6 | Package_TO_SOT_SMD:SOT-23-6 | http://www2.st.com/resource/en/datasheet/CD00050750.pdf |  |  |  |  |  |  |  |  |  | USBLC6-2SC6
 |  | U10 | USBLC6-2SC6 | Power_Protection:USBLC6-2SC6 | Package_TO_SOT_SMD:SOT-23-6 | http://www2.st.com/resource/en/datasheet/CD00050750.pdf |  |  |  |  |  |  |  |  |  | USBLC6-2SC6
 |  | U11 | SN6505 | SN6505:SN6505 | Package_TO_SOT_SMD:SOT-23-6 |  |  |  |  |  |  |  |  |  |  | SN6505BDBVR
 |  | U12 | TCAN332 | Interface_CAN_LIN:TCAN332 | Package_TO_SOT_SMD:SOT-23-8 | http://www.ti.com/lit/ds/symlink/tcan337.pdf |  |  |  |  |  |  |  |  |  | TCAN332DCNR
 |  | U13 | ISL83483 | Interface_UART:ST485EBDR | Package_SO:SOIC-8_3.9x4.9mm_P1.27mm | http://www.st.com/resource/en/datasheet/st485eb.pdf |  |  |  |  |  |  |  |  |  | ISL83483IBZ
 |  | Y1 | 8MHz | Device:Crystal_Small | Crystal:Crystal_SMD_5032-2Pin_5.0x3.2mm | ~ |  |  |  |  |  |  |  |  |  | NX5032GA-8MHZ-EXS00A-CG07039
 |  | Y2 | 32.768KHz | Device:Crystal_Small | Crystal:Crystal_SMD_MicroCrystal_CC7V-T1A-2Pin_3.2x1.5mm | ~ |  |  |  |  |  |  |  |  |  | FC-135 32.7680KA-A5
 |  | Y3 | 25MHz | Device:Crystal_Small | Crystal:Crystal_SMD_5032-2Pin_5.0x3.2mm | ~ |  |  |  |  |  |  |  |  |  | 445C33D25M00000
Collated Components:
Item | Qty | Reference(s) | Value | LibPart | Footprint | Datasheet | Category | DK_Datasheet_Link | DK_Detail_Page | Description | Digi-Key_PN | Family | MPN | Manufacturer | Status | manf#
1 | 26 | C1, C2, C3, C4, C6, C7, C8, C9, C10, C11, C16, C20, C21, C22, C23, C24, C25, C26, C27, C28, C34, C35, C36, C37, C38, C40 | 0.1u | Device:C_Small | Capacitor_SMD:C_0805_2012Metric | ~ |  |  |  |  |  |  |  |  |  | 885012207098
2 | 3 | C5, C18, C19 | 4.7u | Device:C_Small | Capacitor_SMD:C_0805_2012Metric | ~ |  |  |  |  |  |  |  |  |  | LMK212B7475MG-T
3 | 2 | C12, C13 | 18p | Device:C_Small | Capacitor_SMD:C_0805_2012Metric | ~ |  |  |  |  |  |  |  |  |  | CL21C180JBANNNC
4 | 2 | C14, C15 | 10p | Device:C_Small | Capacitor_SMD:C_0805_2012Metric | ~ |  |  |  |  |  |  |  |  |  | 885012007010
5 | 3 | C17, C30, C31 | 2.2u | Device:C_Small | Capacitor_SMD:C_0805_2012Metric | ~ |  |  |  |  |  |  |  |  |  | CL31B225KOHNNNE
6 | 2 | C29, C39 | 10u | Device:C_Small | Capacitor_SMD:C_0805_2012Metric | ~ |  |  |  |  |  |  |  |  |  | CL21A106MQFNNNE
7 | 2 | C32, C33 | 22p | Device:C_Small | Capacitor_SMD:C_0805_2012Metric | ~ |  |  |  |  |  |  |  |  |  | 885012007012
8 | 2 | D1, D10 | NUP2105L | Power_Protection:NUP2105L | Package_TO_SOT_SMD:SOT-23 | http://www.onsemi.com/pub_link/Collateral/NUP2105L-D.PDF |  |  |  |  |  |  |  |  |  | NUP2105L
9 | 6 | D2, D4, D5, D6, D11, D12 | B120-E3 | Diode:B120-E3 | Diode_SMD:D_SMA | http://www.vishay.com/docs/88946/b120.pdf |  |  |  |  |  |  |  |  |  | B120-E3
10 | 1 | D7 | LED_PWR | Device:LED_Small_ALT | LED_SMD:LED_0805_2012Metric_Castellated | ~ |  |  |  |  |  |  |  |  |  | 150080RS75000
11 | 1 | D8 | LED_PA8 | Device:LED_Small_ALT | LED_SMD:LED_0805_2012Metric_Castellated | ~ |  |  |  |  |  |  |  |  |  | 150080RS75000
12 | 4 | H1, H2, H3, H4 | MountingHole | Mechanical:MountingHole_Pad | MountingHole:MountingHole_3.2mm_M3_Pad_Via | ~
13 | 3 | J1, J2, J7 | 10118194-0001LF | dk_USB-DVI-HDMI-Connectors:10118194-0001LF | footprints:USB_Micro_B_Female_10118194-0001LF | http://www.amphenol-icc.com/media/wysiwyg/files/drawing/10118194.pdf | Connectors, Interconnects | http://www.amphenol-icc.com/media/wysiwyg/files/drawing/10118194.pdf | /product-detail/en/amphenol-icc-fci/10118194-0001LF/609-4618-1-ND/2785382 | CONN RCPT USB2.0 MICRO B SMD R/A | 609-4618-1-ND | USB, DVI, HDMI Connectors | 10118194-0001LF | Amphenol ICC (FCI) | Active | 10118194-0001LF
14 | 1 | J3 | RJ45_Amphenol_RJMG1BD3B8K1ANR | Connector:RJ45_Amphenol_RJMG1BD3B8K1ANR | Connector_RJ:RJ45_Amphenol_RJMG1BD3B8K1ANR | https://www.amphenolcanada.com/ProductSearch/Drawings/AC/RJMG1BD3B8K1ANR.PDF |  |  |  |  |  |  |  |  |  | RJMG1BD3B8K1ANR
15 | 1 | J4 | Micro_SD_Card | trololo-rescue:Micro_SD_Card-Connector | Connector_Card:microSD_HC_Hirose_DM3D-SF | http://katalog.we-online.de/em/datasheet/693072010801.pdf |  |  |  |  |  |  |  |  |  | DM3D-SF
16 | 1 | J5 | Screw_Terminal_01x06 | Connector:Screw_Terminal_01x06 | Connector_Phoenix_MC:PhoenixContact_MC_1,5_6-GF-3.5_1x06_P3.50mm_Horizontal_ThreadedFlange_MountHole | ~ |  |  |  |  |  |  |  |  |  | 1985234
17 | 3 | J6, J9, J10 | Conn_02x12_Odd_Even | Connector_Generic:Conn_02x12_Odd_Even | Connector_PinSocket_2.54mm:PinSocket_2x12_P2.54mm_Vertical | ~
18 | 1 | J8 | Screw_Terminal_01x02 | Connector:Screw_Terminal_01x02 | Connector_Phoenix_MC:PhoenixContact_MC_1,5_2-GF-3.5_1x02_P3.50mm_Horizontal_ThreadedFlange_MountHole | ~ |  |  |  |  |  |  |  |  |  | 1985195
19 | 1 | J11 | Conn_02x02_Odd_Even | Connector_Generic:Conn_02x02_Odd_Even | Connector_PinHeader_2.54mm:PinHeader_2x02_P2.54mm_Vertical | ~
20 | 2 | J13, J18 | PROTO1 | Connector_Generic:Conn_02x10_Odd_Even | Connector_PinHeader_2.54mm:PinHeader_2x10_P2.54mm_Vertical | ~
21 | 1 | JP1 | BOOT | Device:Jumper_NC_Small | Connector_PinHeader_2.54mm:PinHeader_1x02_P2.54mm_Horizontal | ~
22 | 2 | JP2, JP3 | Jumper_2_Bridged | Jumper:Jumper_2_Bridged | Jumper:SolderJumper-2_P1.3mm_Bridged_RoundedPad1.0x1.5mm | ~
23 | 2 | JP4, JP5 | Jumper_2_Bridged | Jumper:Jumper_2_Bridged | Jumper:SolderJumper-2_P1.3mm_Open_RoundedPad1.0x1.5mm | ~
24 | 1 | L1 | 68uH | Device:L_Small | Inductor_SMD:L_6.3x6.3_H3 | ~ |  |  |  |  |  |  |  |  |  | 1255AY-3R9N=P3
25 | 7 | R1, R2, R3, R4, R5, R7, R11 | 4K7 | Device:R_Small | Resistor_SMD:R_0805_2012Metric | ~ |  |  |  |  |  |  |  |  |  | RC0805JR-074K7L
26 | 1 | R6 | 6.49K 1% | Device:R_Small | Resistor_SMD:R_0805_2012Metric | ~ |  |  |  |  |  |  |  |  |  | RMCF0805FT6K49
27 | 3 | R8, R9, R10 | 220R | Device:R_Small | Resistor_SMD:R_0805_2012Metric | ~ |  |  |  |  |  |  |  |  |  | CRGCQ0805J22R
28 | 1 | SW1 | RESET | Switch:SW_Push | Button_Switch_SMD:SW_SPST_TL3342 | ~ |  |  |  |  |  |  |  |  |  | TL3342
29 | 1 | SW2 | PC13 | Switch:SW_Push | Button_Switch_THT:SW_Tactile_SPST_Angled_PTS645Vx31-2LFS | ~ |  |  |  |  |  |  |  |  |  | PTS645VM31-2 LFS
30 | 1 | TR1 | ADTT1-6 | Transformer:ADTT1-6 | Transformer_SMD:Pulse_P0926NL | https://ww2.minicircuits.com/pdfs/ADTT1-6+.pdf |  |  |  |  |  |  |  |  |  | 750315371
31 | 1 | U1 | STM32H743VITx | MCU_ST_STM32H7:STM32H743VITx | Package_QFP:LQFP-100_14x14mm_P0.5mm | http://www.st.com/st-web-ui/static/active/en/resource/technical/document/datasheet/DM00387108.pdf |  |  |  |  |  |  |  |  |  | STM32H743VIT6
32 | 1 | U2 | KSZ8081RNA | Interface_Ethernet:KSZ8081RNA | Package_DFN_QFN:QFN-24-1EP_4x4mm_P0.5mm_EP2.6x2.6mm | http://ww1.microchip.com/downloads/en/DeviceDoc/00002199A.pdf |  |  |  |  |  |  |  |  |  | KSZ8081RNA
33 | 1 | U3 | ISO1050DUB | trololo-rescue:ISO1050DUB-Interface_CAN_LIN | Package_SO:SOP-8_6.62x9.15mm_P2.54mm | http://www.ti.com/lit/ds/symlink/iso1050.pdf |  |  |  |  |  |  |  |  |  | ISO1050DUB
34 | 1 | U4 | ISO3082DW | Interface_UART:ISO3082DW | Package_SO:SOIC-16W_7.5x10.3mm_P1.27mm | http://www.ti.com/lit/ds/symlink/iso3082.pdf |  |  |  |  |  |  |  |  |  | ISO3082DW
35 | 1 | U5 | S25FL127SABMFI101 | 2019-03-05_02-01-41:S25FL127SABMFI101 | footprints:S25FL127SABMFI101 |  |  |  |  |  |  |  |  |  |  | S25FL127SABMFI101
36 | 1 | U6 | AP63203 | reg_ap6320x:AP63203 | Package_TO_SOT_SMD:TSOT-23-6 |  |  |  |  |  |  |  |  |  |  | AP63203WU-7
37 | 3 | U7, U9, U10 | USBLC6-2SC6 | Power_Protection:USBLC6-2SC6 | Package_TO_SOT_SMD:SOT-23-6 | http://www2.st.com/resource/en/datasheet/CD00050750.pdf |  |  |  |  |  |  |  |  |  | USBLC6-2SC6
38 | 1 | U8 | STM32F042F6Px | MCU_ST_STM32F0:STM32F042F4Px | Package_SO:TSSOP-20_4.4x6.5mm_P0.65mm | http://www.st.com/st-web-ui/static/active/en/resource/technical/document/datasheet/DM00105814.pdf |  |  |  |  |  |  |  |  |  | STM32F042F6P6
39 | 1 | U11 | SN6505 | SN6505:SN6505 | Package_TO_SOT_SMD:SOT-23-6 |  |  |  |  |  |  |  |  |  |  | SN6505BDBVR
40 | 1 | U12 | TCAN332 | Interface_CAN_LIN:TCAN332 | Package_TO_SOT_SMD:SOT-23-8 | http://www.ti.com/lit/ds/symlink/tcan337.pdf |  |  |  |  |  |  |  |  |  | TCAN332DCNR
41 | 1 | U13 | ISL83483 | Interface_UART:ST485EBDR | Package_SO:SOIC-8_3.9x4.9mm_P1.27mm | http://www.st.com/resource/en/datasheet/st485eb.pdf |  |  |  |  |  |  |  |  |  | ISL83483IBZ
42 | 1 | Y1 | 8MHz | Device:Crystal_Small | Crystal:Crystal_SMD_5032-2Pin_5.0x3.2mm | ~ |  |  |  |  |  |  |  |  |  | NX5032GA-8MHZ-EXS00A-CG07039
43 | 1 | Y2 | 32.768KHz | Device:Crystal_Small | Crystal:Crystal_SMD_MicroCrystal_CC7V-T1A-2Pin_3.2x1.5mm | ~ |  |  |  |  |  |  |  |  |  | FC-135 32.7680KA-A5
44 | 1 | Y3 | 25MHz | Device:Crystal_Small | Crystal:Crystal_SMD_5032-2Pin_5.0x3.2mm | ~ |  |  |  |  |  |  |  |  |  | 445C33D25M00000

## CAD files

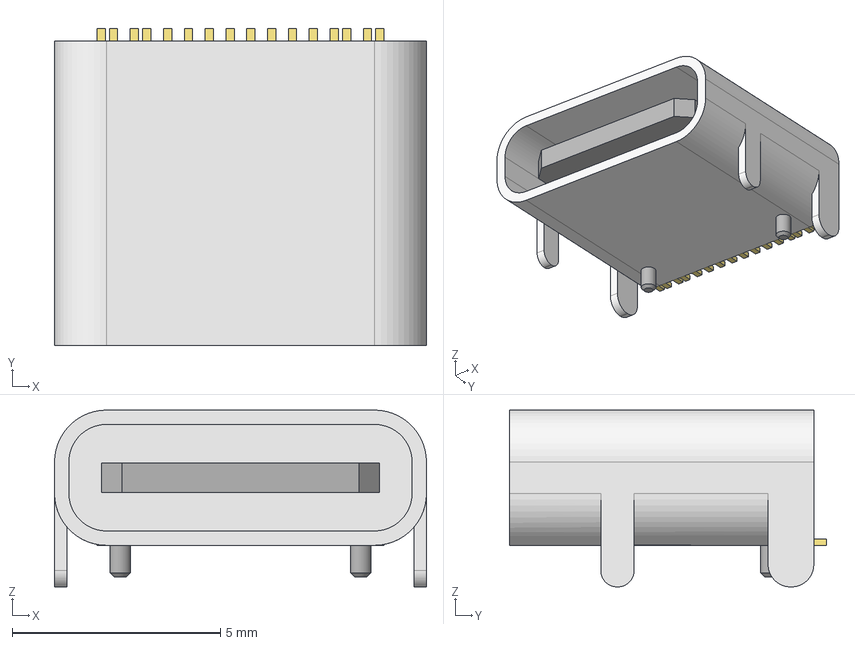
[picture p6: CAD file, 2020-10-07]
package.3d/USB_C_Receptacle_Palconn_UTC16-G.step
8.94 x 7.63 x 4.25 mm

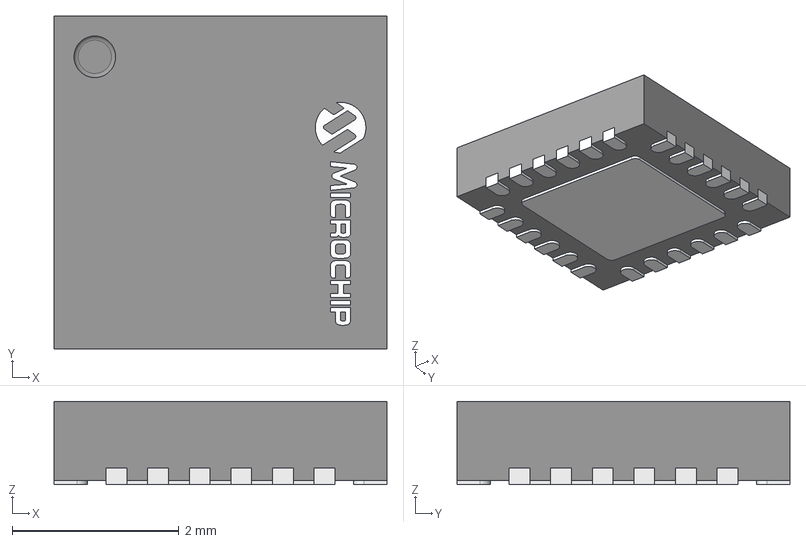
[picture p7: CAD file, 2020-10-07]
package.3d/Microchip_-_LAN8742A-CZ-TR.step
4.00 x 4.00 x 1.00 mm
pisn
logo

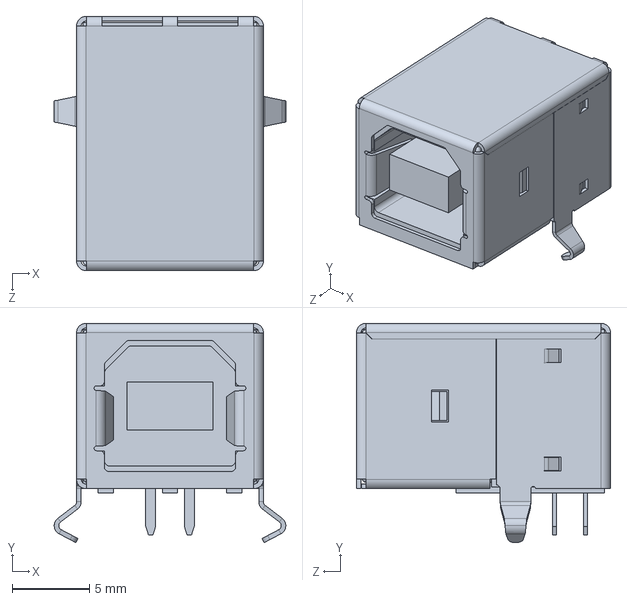
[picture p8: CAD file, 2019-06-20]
package.3d/CUI_UJ2-BH-1-TH.step
15.0 x 14.2 x 16.5 mm

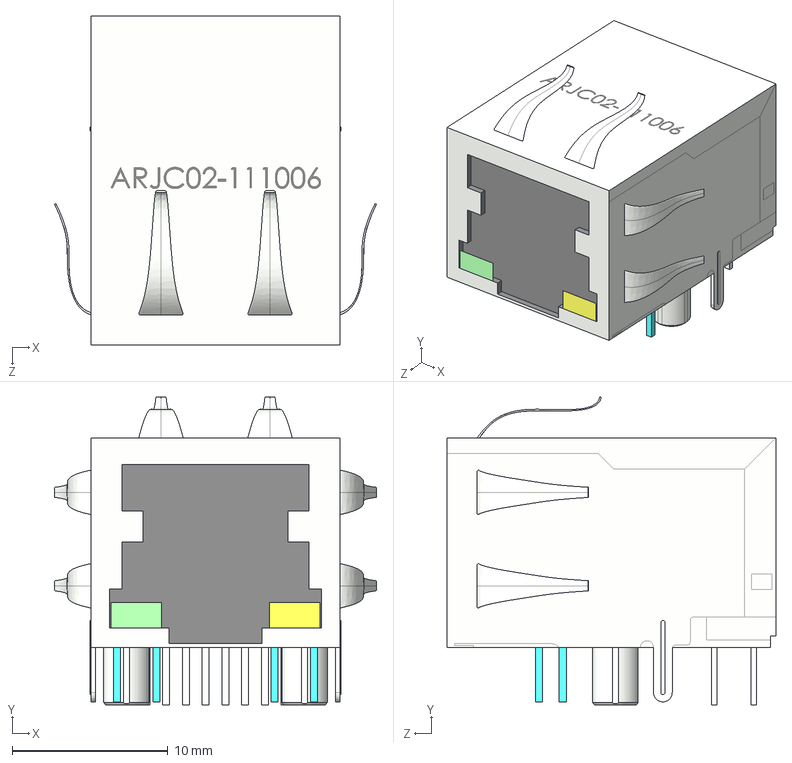
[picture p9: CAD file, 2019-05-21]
package.3d/ARJC02-111006.STEP
20.7 x 19.8 x 21.1 mm

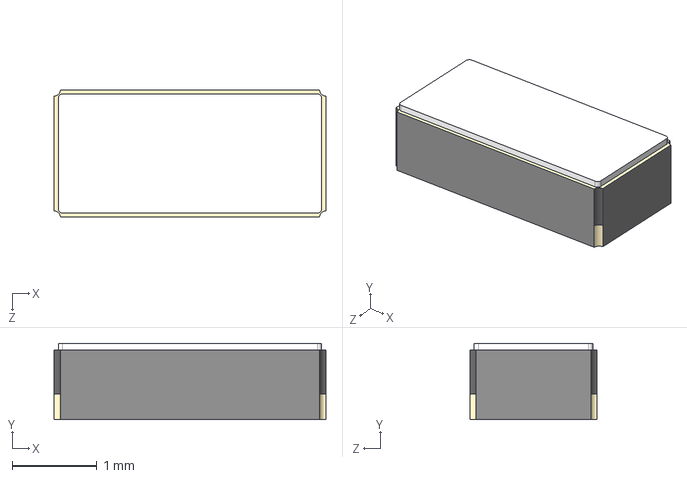
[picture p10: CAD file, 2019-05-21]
package.3d/ECS-.327-12.5-34B-C-TR--3DModel-STEP-40055.STEP
3.20 x 0.9 x 1.50 mm

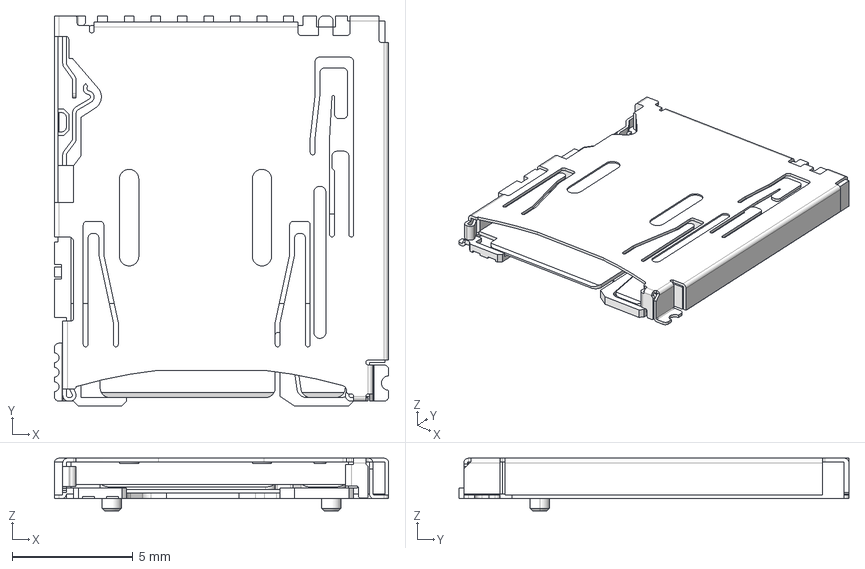
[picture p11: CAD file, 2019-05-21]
package.3d/DM3AT-SF-PEJ2M5.stp
13.8 x 16.2 x 2.18 mm

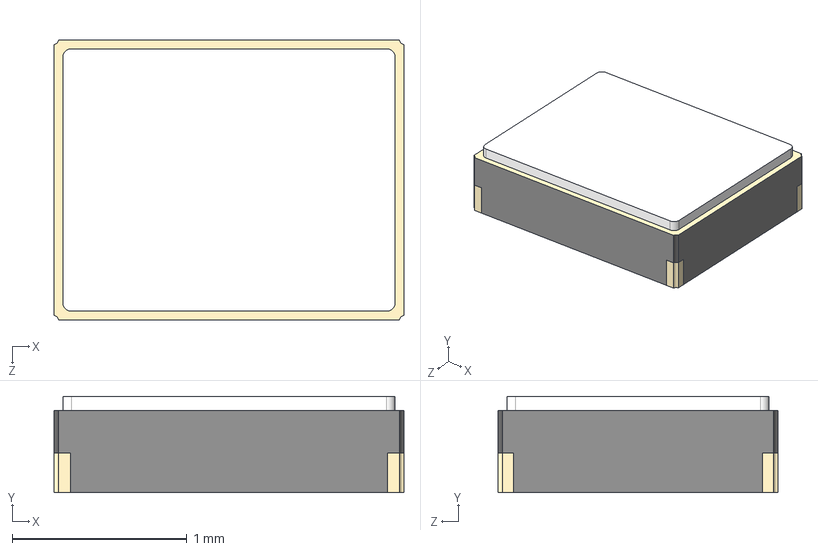
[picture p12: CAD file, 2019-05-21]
package.3d/ECS-160-10-37-RWM-TR--3DModel-STEP-40055.STEP
2.00 x 0.55 x 1.60 mm

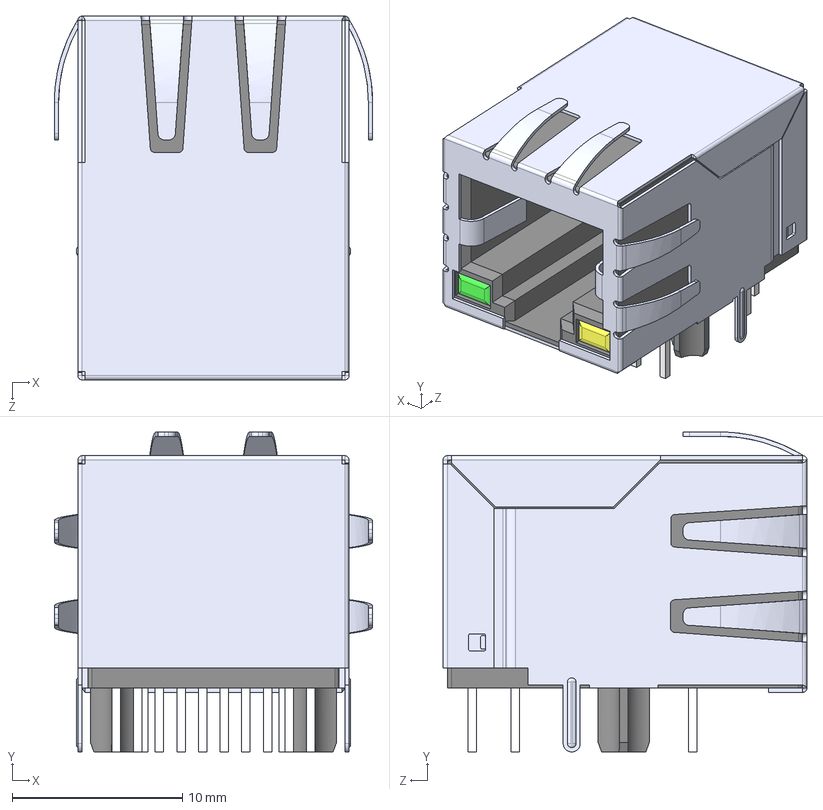
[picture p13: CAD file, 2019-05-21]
package.3d/JXD0-0001NL--3DModel-STEP-56544.STEP
18.7 x 18.8 x 21.4 mm

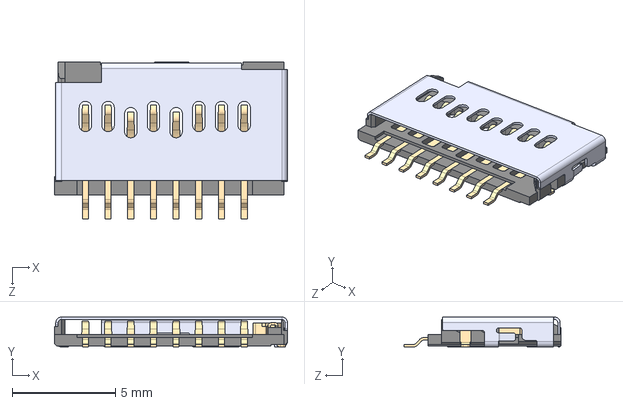
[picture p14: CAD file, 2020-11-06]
package.3d/105162-0001.step
11.3 x 1.45 x 7.60 mm

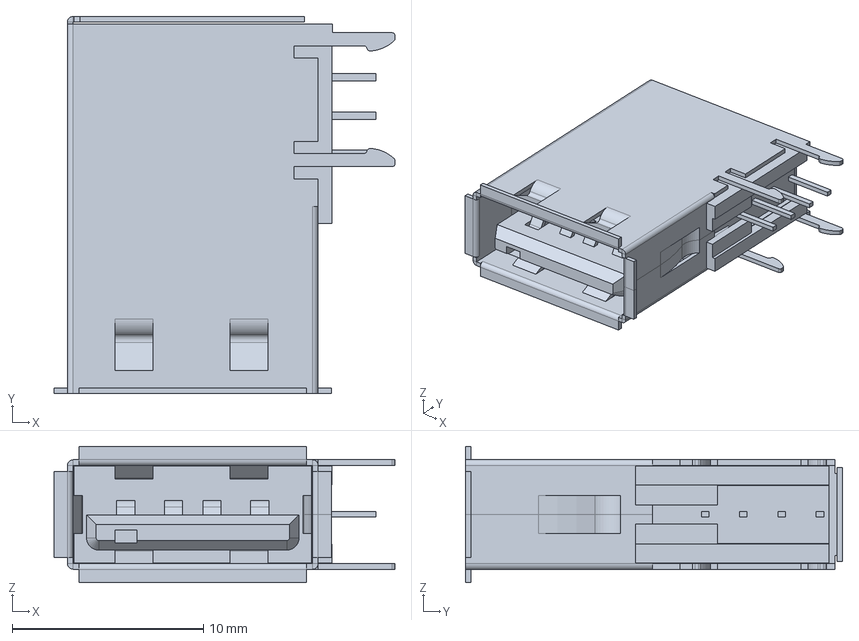
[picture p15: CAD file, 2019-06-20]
package.3d/73725-0110blfc.stp
17.8 x 19.7 x 7.12 mm

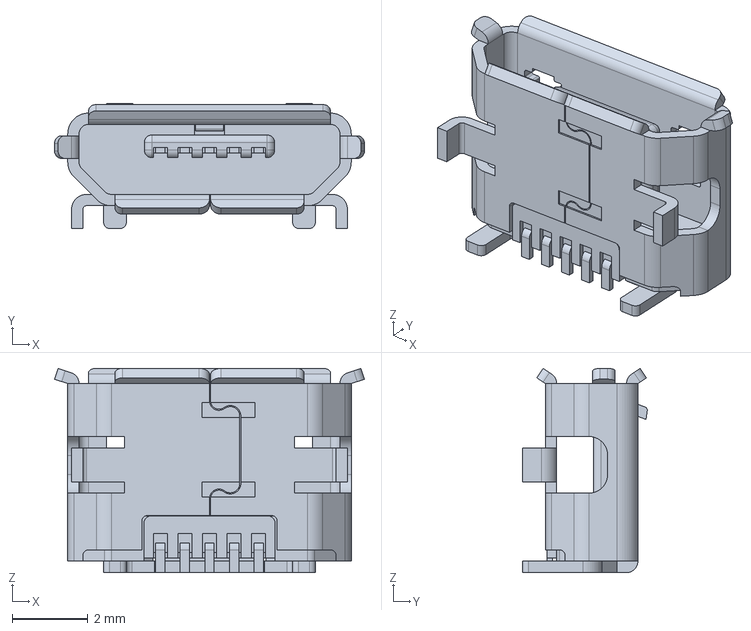
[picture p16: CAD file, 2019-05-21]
package.3d/1050170001.stp
8.20 x 3.30 x 5.40 mm

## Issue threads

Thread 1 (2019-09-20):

Test board design

martinribelotta, 2019-09-20:
Peripheral checklist:

 - [X] Power
 - [X] CPU
 - [X] Boot: Fixed invert bootloader polarity. Workaround using jumper for normal operation
 - [X] Reset
 - [X] Debug: Fixed invert bootloader polarity. Workaround using jumper for normal operation
 - [X] User LED
 - [X] User Button
 - [X] Clock 8MHz
 - [X] USB Dev
 - [X] SD Card: Fixed no pullup, workaround using internal pullup
 - [ ] QSPI
 - [ ] Clock 32.768Khz
 - [ ] CAN
 - [ ] RS485
 - [ ] ETH
 - [ ] USB Host
 - [ ] RTC Battery retention

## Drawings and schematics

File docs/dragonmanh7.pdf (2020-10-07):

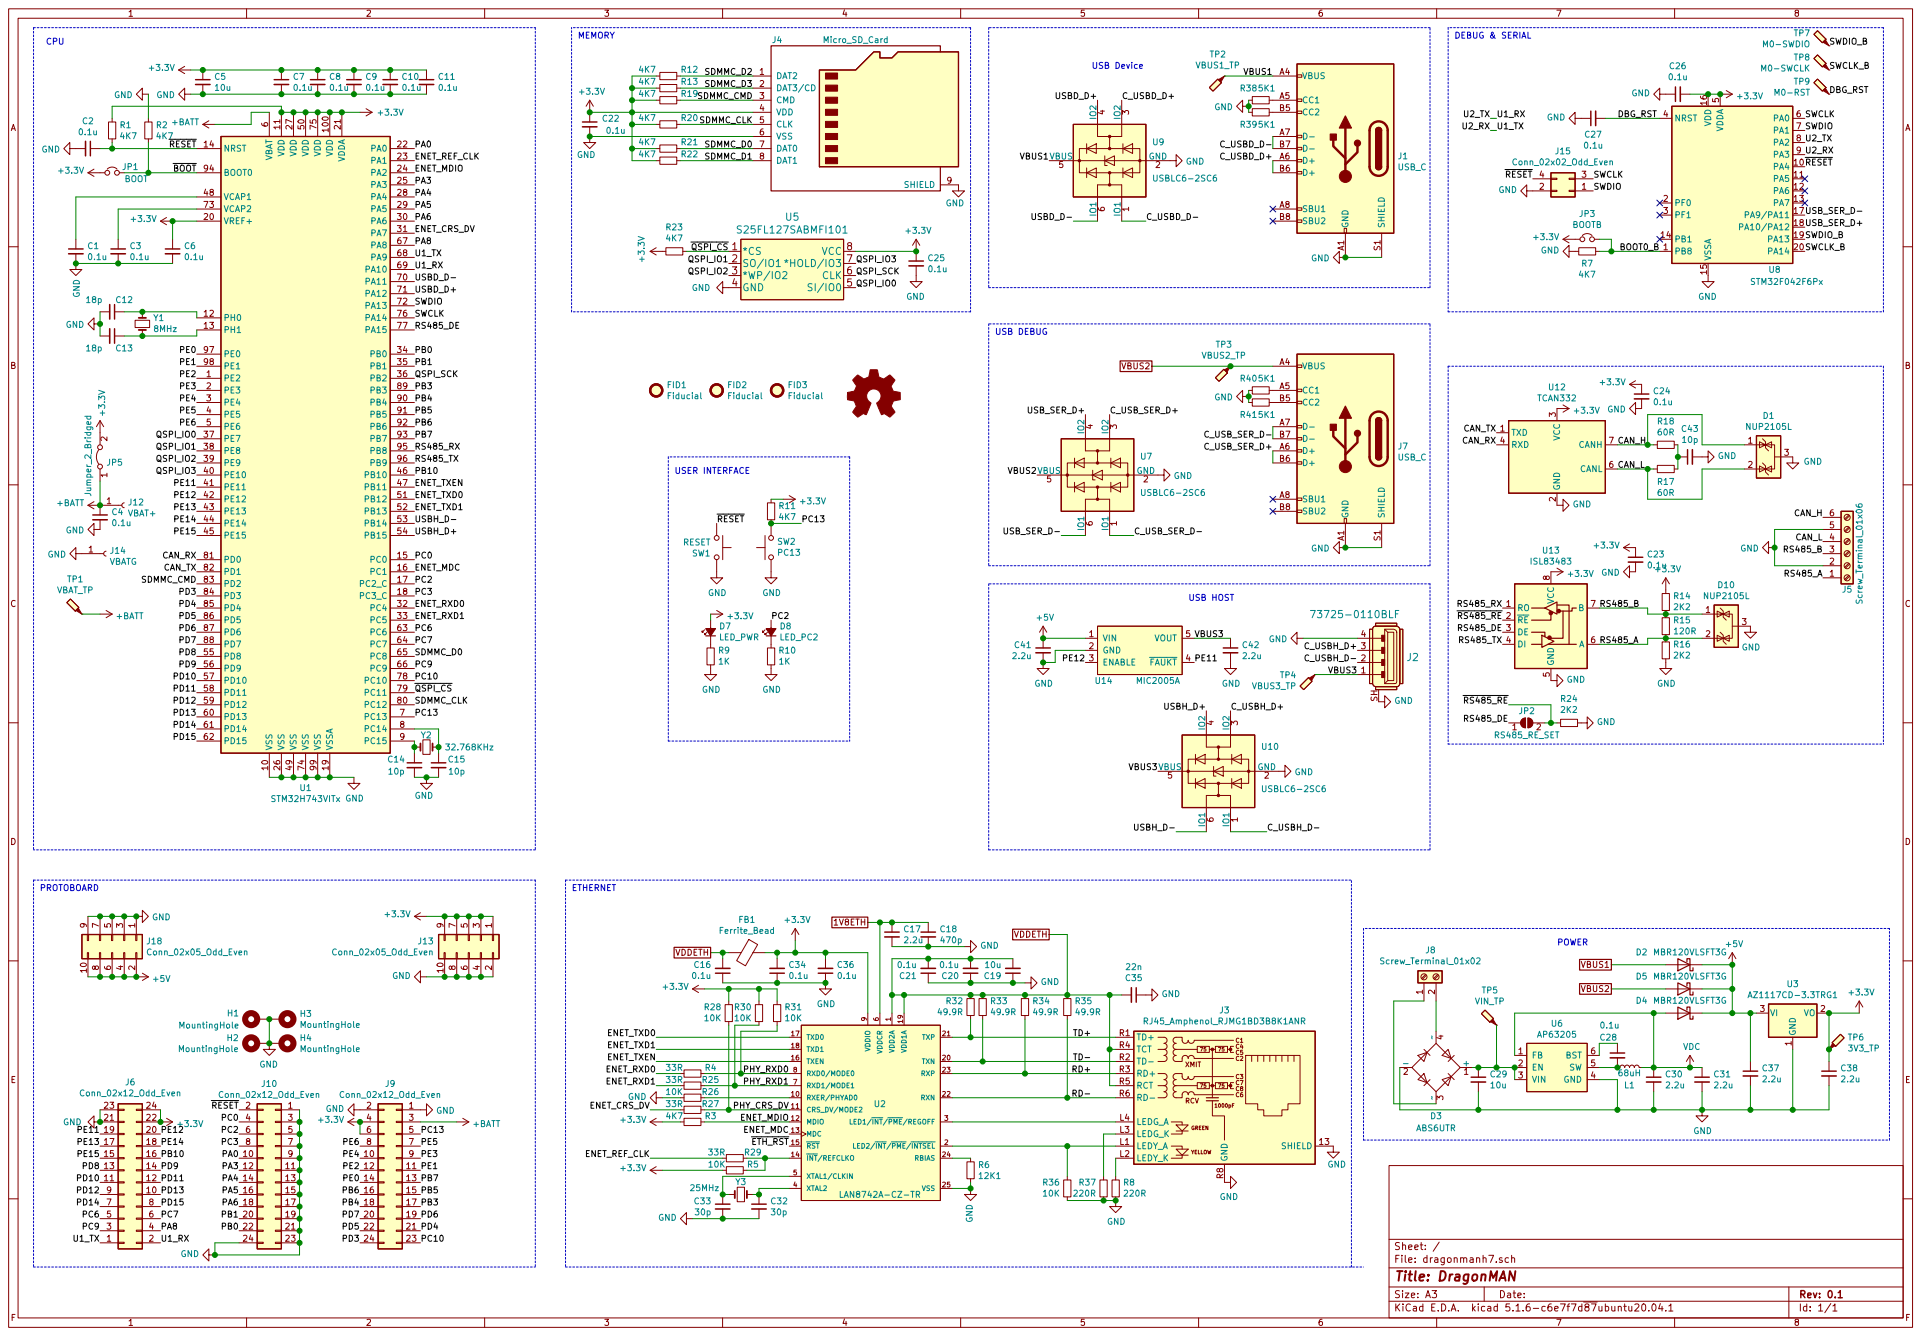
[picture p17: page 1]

6 VCAP1 48 VCAP2 73 VDD 100 VDD 11 VDD 27 VDD 50 VDD 75 VDDA 21 VREF+ 20 VSS 10 VSS 26 VSS 49 VSS 74 VSS 99 VSSA 19 U1 STM32H743VITx 1

3 RXD 4 CANL 6 CANH 7 U12 TCAN332 GND GND

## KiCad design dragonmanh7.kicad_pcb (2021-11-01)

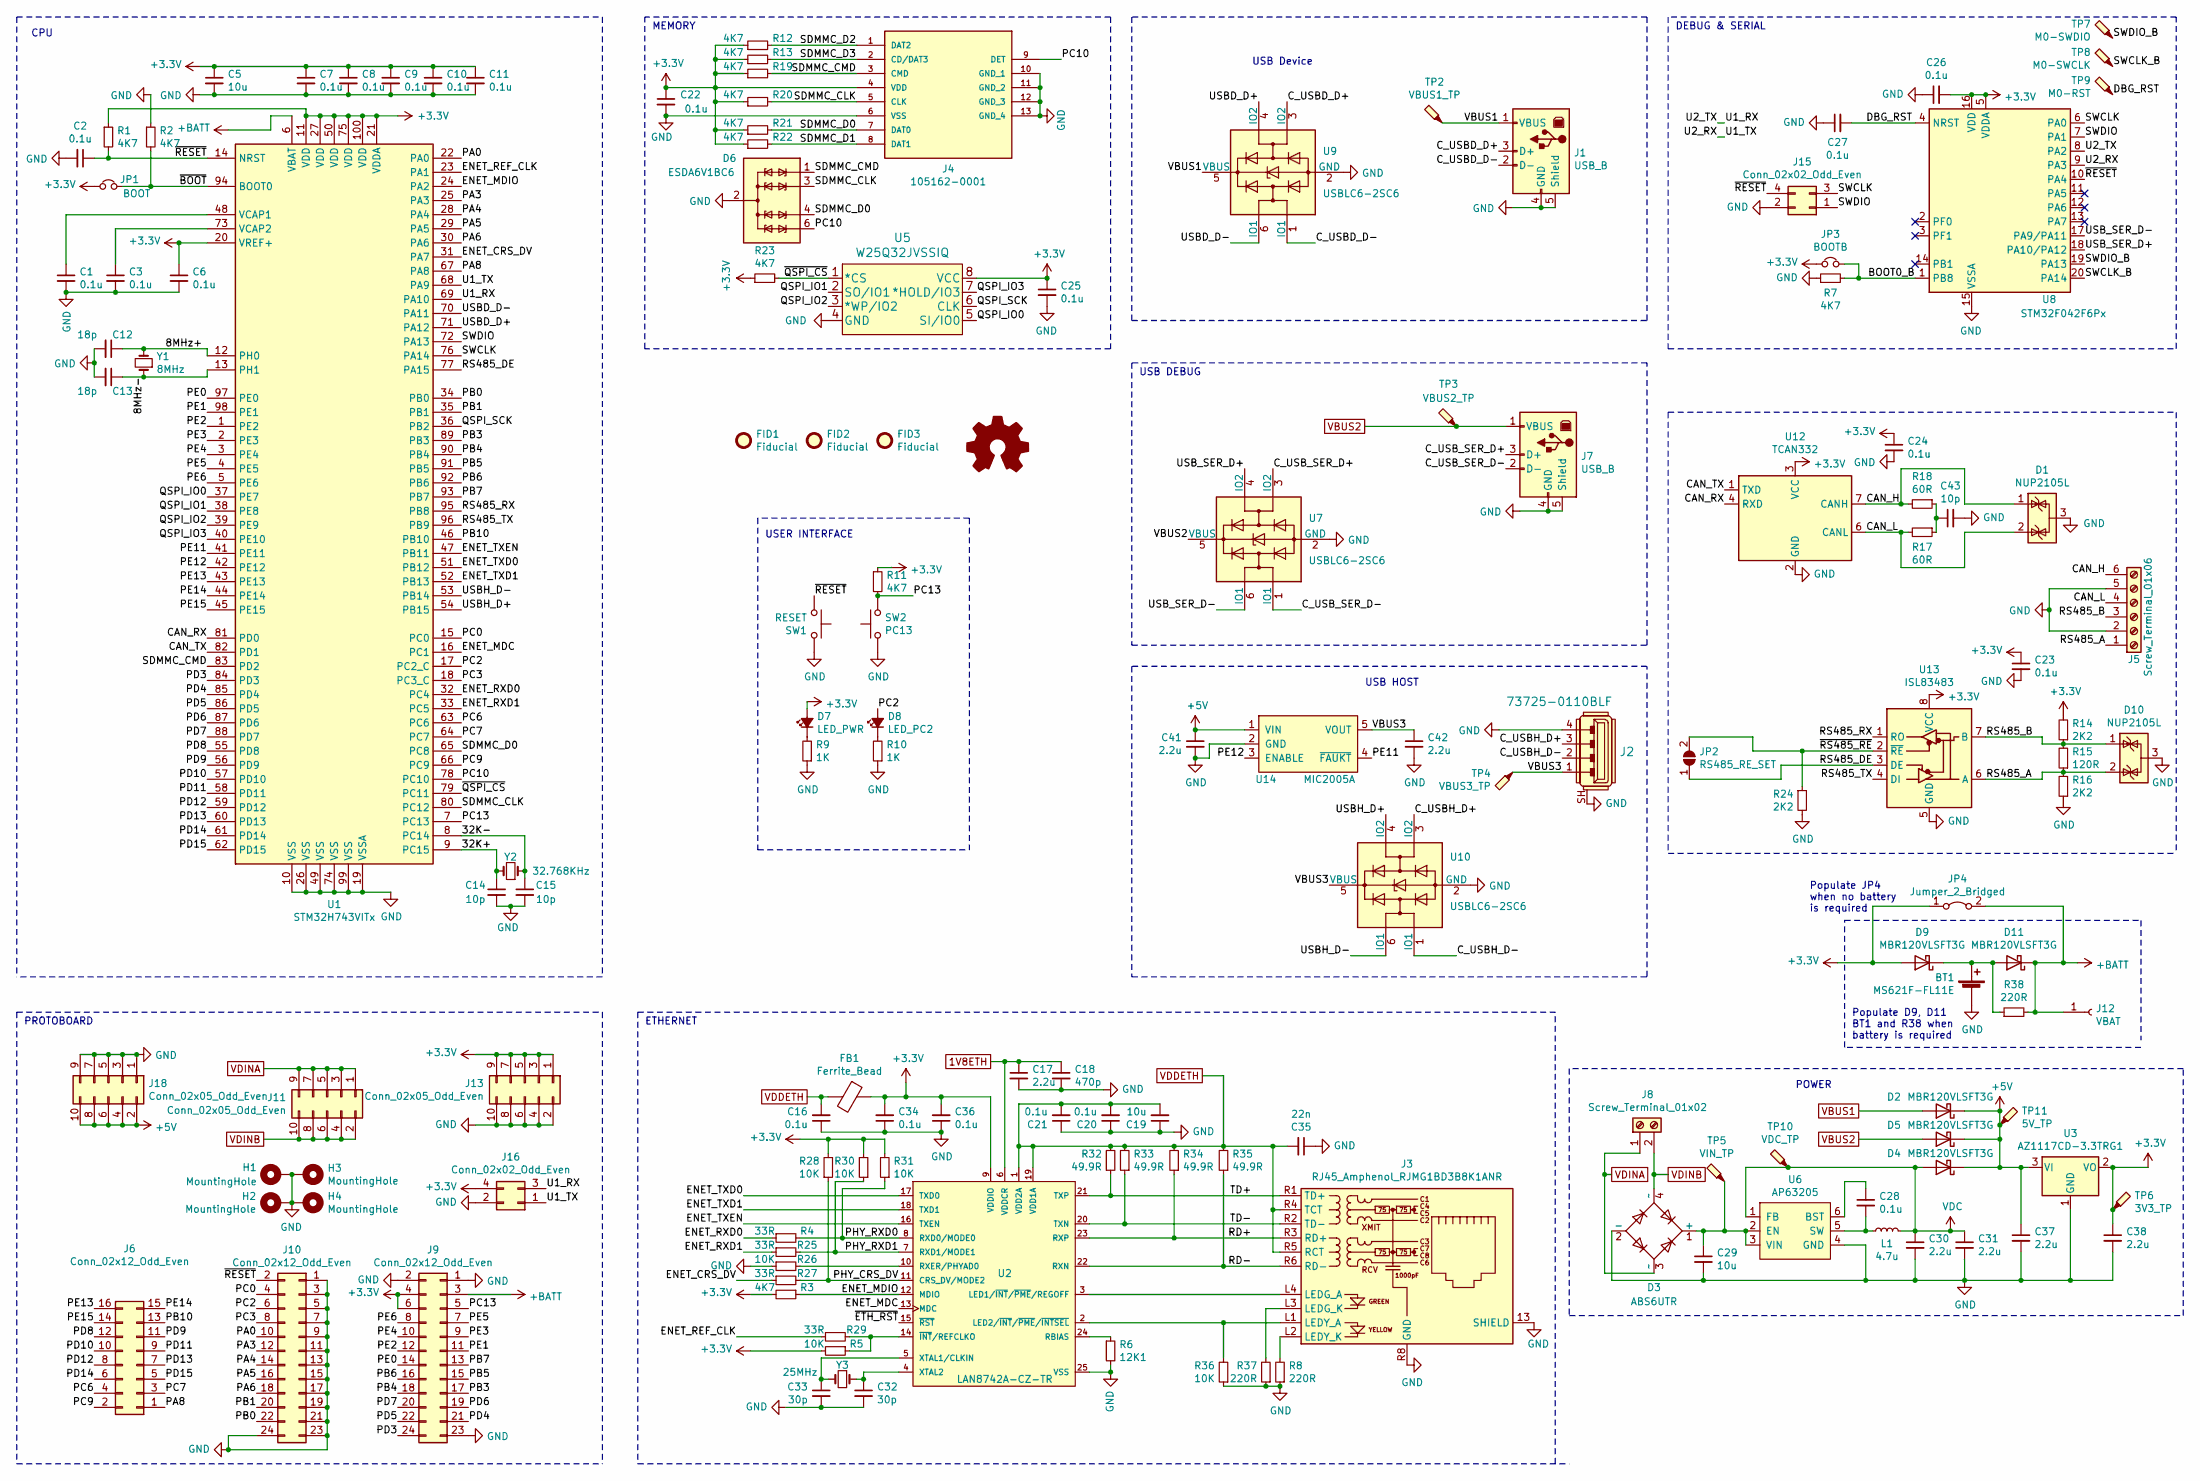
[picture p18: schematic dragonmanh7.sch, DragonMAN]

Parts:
BT1: MS621F-FL11E; BatteryHolder_Seiko_MS621F
C1, C2, C3, C6, C7, C8, C9, C10, C11, C16, C20, C21, C22, C23, C24, C25, C26, C27, C28, C34, C36: 0.1u; C_0603_1608Metric
C5, C19, C29: 10u; C_0805_2012Metric
C12, C13: 18p; C_0603_1608Metric
C14, C15, C43: 10p; C_0603_1608Metric
C17, C30, C31, C37, C38, C41, C42: 2.2u; C_0805_2012Metric
C18: 470p; C_0603_1608Metric
C32, C33: 30p; C_0603_1608Metric
C35: 22n; C_0603_1608Metric
D1, D10: NUP2105L; SOT-23
D2, D4, D5, D9, D11: MBR120VLSFT3G; D_SOD-123F
D3: ABS6UTR; Diode_Bridge_Diotec_ABS
D6: ESDA6V1BC6; SOT-23-6
D7: LED_PWR; LED_0805_2012Metric_Castellated
D8: LED_PC2; LED_0805_2012Metric_Castellated
FB1: Ferrite_Bead; L_0603_1608Metric
FID1, FID2, FID3: Fiducial; Fiducial_1mm_Mask2mm
H1, H2, H3, H4: MountingHole; MountingHole_3.2mm_M3_Pad_Via
J1, J7: USB_B; USB_B_Lumberg_2411_02_Horizontal
J2: 73725-0110BLF; USB_A_Female_Vertical_RA_73725-0110BLF; MPN 73725-0110BLF; Digi-Key_PN 609-1041-ND
J3: RJ45_Amphenol_RJMG1BD3B8K1ANR
J4: 105162-0001; MANUFACTURER_PART_NUMBER 105162-0001; MOUSER_PART_NUMBER 538-105162-0001
J5: Screw_Terminal_01x06; PhoenixContact_MC-G_06x5.08mm_Angled
J6: Conn_02x12_Odd_Even; PinSocket_2x08_P2.54mm_Vertical
J8: Screw_Terminal_01x02; PhoenixContact_MC-G_02x5.08mm_Angled
J9, J10: Conn_02x12_Odd_Even; PinSocket_2x12_P2.54mm_Vertical
J11, J13, J18: Conn_02x05_Odd_Even; PinSocket_2x05_P2.54mm_Vertical
J12: VBAT; TestPoint_Loop_D1.80mm_Drill1.0mm_Beaded
J15: Conn_02x02_Odd_Even; Pin_Header_Straight_2x02_Pitch2.54mm
J16: Conn_02x02_Odd_Even; PinSocket_2x02_P2.54mm_Vertical
JP1: BOOT; PinHeader_1x02_P2.54mm_Horizontal
JP2: RS485_RE_SET; SolderJumper-2_P1.3mm_Open_RoundedPad1.0x1.5mm
JP3: BOOTB; PinHeader_1x02_P2.54mm_Vertical
JP4: Jumper_2_Bridged; SolderJumper-2_P1.3mm_Open_RoundedPad1.0x1.5mm
L1: 4.7u; L_6.3x6.3_H3
LOGO1: Logo_Open_Hardware_Small; KiCad-Logo2_8mm_SilkScreen
R1, R2, R3, R7, R11, R12, R13, R19, R20, R21, R22, R23: 4K7; R_0603_1608Metric
R4, R25, R27, R29: 33R; R_0603_1608Metric
R5, R26, R28, R30, R31, R36: 10K; R_0603_1608Metric
R6: 12K1; R_0603_1608Metric
R8, R37, R38: 220R; R_0603_1608Metric
R9, R10: 1K; R_0603_1608Metric
R14, R16, R24: 2K2; R_0603_1608Metric
R15: 120R; R_0603_1608Metric
R17, R18: 60R; R_0603_1608Metric
R32, R33, R34, R35: 49.9R; R_0603_1608Metric
SW1: RESET; SW_Tactile_SPST_Angled_PTS645Vx31-2LFS
SW2: PC13; SW_Tactile_SPST_Angled_PTS645Vx31-2LFS
TP2: VBUS1_TP; TestPoint_Pad_D2.5mm
TP3: VBUS2_TP; TestPoint_Pad_D2.5mm
TP4: VBUS3_TP; TestPoint_Pad_D2.5mm
TP5: VIN_TP; TestPoint_Pad_D2.5mm
TP6: 3V3_TP; TestPoint_Pad_D2.5mm
TP7: M0-SWDIO; TestPoint_Pad_1.0x1.0mm
TP8: M0-SWCLK; TestPoint_Pad_1.0x1.0mm
TP9: M0-RST; TestPoint_Pad_1.0x1.0mm
TP10: VDC_TP; TestPoint_Pad_D2.5mm
TP11: 5V_TP; TestPoint_Pad_D2.5mm
U1: STM32H743VITx; LQFP-100_14x14mm_P0.5mm
U2: LAN8742A-CZ-TR; Microchip-C04-143B-S4QFN-0-0-IPC_C; mouser part number 579-LAN8742A-CZ-TR; digikey description IC TRANSCEIVER 1/1 24SQFN
U3: AZ1117CD-3.3TRG1; TO-252-2
U5: W25Q32JVSSIQ; S25FL127SABMFI101
U6: AP63205; TSOT-23-6
U7, U9, U10: USBLC6-2SC6; SOT-23-6
U8: STM32F042F6Px; TSSOP-20_4.4x6.5mm_P0.65mm
U12: TCAN332; SOT-23-8
U13: ISL83483; SOIC-8_3.9x4.9mm_P1.27mm
U14: MIC2005A; SOT-23-5
Y1: 8MHz; Crystal_SMD_5032-2Pin_5.0x3.2mm
Y2: 32.768KHz; Crystal_SMD_MicroCrystal_CC7V-T1A-2Pin_3.2x1.5mm
Y3: 25MHz; Crystal_SMD_5032-2Pin_5.0x3.2mm

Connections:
1V8ETH: C17.1, C18.1, U2.6 (VDDCR)
+3V3: C5.1, C6.1, C7.1, C8.1, C9.1, C10.1, C11.1, C22.1, C23.1, C24.1, C25.1, C26.2, C34.2, C36.2, C38.1, D7.2 (A), D9.2 (A), FB1.1, J4.4 (VDD), J9.4, J9.6, J13.1, J13.3, J13.5, J13.7, J13.9, J16.4, JP1.1, JP3.1, JP4.1 (A), R1.1, R3.2, R5.2, R11.1, R12.1, R13.1, R14.2, R19.1, R20.1, R21.1, R22.1, R23.1, R28.2, R30.2, R31.2, TP6.1, U1.11 (VDD), U1.20 (VREF+), U1.21 (VDDA), U1.27 (VDD), U1.50 (VDD), U1.75 (VDD), U1.100 (VDD), U2.9 (VDDIO), U3.2 (VO), U5.8 (VCC), U8.5 (VDDA), U8.16 (VDD), U12.3 (VCC), U13.8 (VCC)
+5V: C37.1, C41.1, D2.1 (K), D4.1 (K), D5.1 (K), J18.2, J18.4, J18.6, J18.8, J18.10, TP11.1, U3.3 (VI), U14.1 (VIN)
+BATT: D11.1 (K), J9.3, J12.1, JP4.2 (B), R38.2, U1.6 (VBAT)
/8MHz+: C12.1, U1.12 (PH0), Y1.2
/8MHz-: C13.1, U1.13 (PH1), Y1.1
/32K+: C14.1, U1.9 (PC15), Y2.2
/32K-: C15.1, U1.8 (PC14), Y2.1
/BOOT0_B: JP3.2, R7.2, U8.1 (PB8)
/CAN_H: D1.1 (K), J5.6, R18.2, U12.7 (CANH)
/CAN_L: D1.2 (K), J5.4, R17.2, U12.6 (CANL)
/CAN_RX: U1.81 (PD0), U12.4 (RXD)
/CAN_TX: U1.82 (PD1), U12.1 (TXD)
/C_USBD_D+: J1.3 (D+), U9.3 (IO2)
/C_USBD_D-: J1.2 (D-), U9.1 (IO1)
/C_USBH_D+: J2.3, U10.3 (IO2)
/C_USBH_D-: J2.2, U10.1 (IO1)
/C_USB_SER_D+: J7.3 (D+), U7.3 (IO2)
/C_USB_SER_D-: J7.2 (D-), U7.1 (IO1)
/DBG_RST: C27.2, TP9.1, U8.4 (NRST)
/ENET_CRS_DV: R27.1, U1.31 (PA7)
/ENET_MDC: U1.16 (PC1), U2.13 (MDC)
/ENET_MDIO: R3.1, U1.24 (PA2), U2.12 (MDIO)
/ENET_REF_CLK: R29.1, U1.23 (PA1)
/ENET_RXD0: R4.1, U1.32 (PC4)
/ENET_RXD1: R25.1, U1.33 (PC5)
/ENET_TXD0: U1.51 (PB12), U2.17 (TXD0)
/ENET_TXD1: U1.52 (PB13), U2.18 (TXD1)
/ENET_TXEN: U1.47 (PB11), U2.16 (TXEN)
/PA0: J10.10, U1.22 (PA0)
/PA3: J10.12, U1.25 (PA3)
/PA4: J10.14, U1.28 (PA4)
/PA5: J10.16, U1.29 (PA5)
/PA6: J10.18, U1.30 (PA6)
/PA8: J6.1, U1.67 (PA8)
/PB0: J10.22, U1.34 (PB0)
/PB1: J10.20, U1.35 (PB1)
/PB3: J9.17, U1.89 (PB3)
/PB4: J9.18, U1.90 (PB4)
/PB5: J9.15, U1.91 (PB5)
/PB6: J9.16, U1.92 (PB6)
/PB7: J9.13, U1.93 (PB7)
/PB10: J6.13, U1.46 (PB10)
/PC0: J10.4, U1.15 (PC0)
/PC2: D8.2 (A), J10.6, U1.17 (PC2_C)
/PC3: J10.8, U1.18 (PC3_C)
/PC6: J6.4, U1.63 (PC6)
/PC7: J6.3, U1.64 (PC7)
/PC9: J6.2, U1.66 (PC9)
/PC10: D6.6 (TVS4), J4.9 (DET), U1.78 (PC10)
/PC13: J9.5, R11.2, SW2.2, U1.7 (PC13)
/PD3: J9.24, U1.84 (PD3)
/PD4: J9.21, U1.85 (PD4)
/PD5: J9.22, U1.86 (PD5)
/PD6: J9.19, U1.87 (PD6)
/PD7: J9.20, U1.88 (PD7)
/PD8: J6.12, U1.55 (PD8)
/PD9: J6.11, U1.56 (PD9)
/PD10: J6.10, U1.57 (PD10)
/PD11: J6.9, U1.58 (PD11)
/PD12: J6.8, U1.59 (PD12)
/PD13: J6.7, U1.60 (PD13)
/PD14: J6.6, U1.61 (PD14)
/PD15: J6.5, U1.62 (PD15)
/PE0: J9.14, U1.97 (PE0)
/PE1: J9.11, U1.98 (PE1)
/PE2: J9.12, U1.1 (PE2)
/PE3: J9.9, U1.2 (PE3)
/PE4: J9.10, U1.3 (PE4)
/PE5: J9.7, U1.4 (PE5)
/PE6: J9.8, U1.5 (PE6)
/PE11: U1.41 (PE11), U14.4 (~FAUKT)
/PE12: U1.42 (PE12), U14.3 (ENABLE)
/PE13: J6.16, U1.43 (PE13)
/PE14: J6.15, U1.44 (PE14)
/PE15: J6.14, U1.45 (PE15)
/PHY_CRS_DV: R27.2, R28.1, U2.11 (CRS_DV/MODE2)
/PHY_RXD0: R4.2, R31.1, U2.8 (RXD0/MODE0)
/PHY_RXD1: R25.2, R30.1, U2.7 (RXD1/MODE1)
/QSPI_IO0: U1.37 (PE7), U5.5 (SI/IO0)
/QSPI_IO1: U1.38 (PE8), U5.2 (SO/IO1)
/QSPI_IO2: U1.39 (PE9), U5.3 (*WP/IO2)
/QSPI_IO3: U1.40 (PE10), U5.7 (*HOLD/IO3)
/QSPI_SCK: U1.36 (PB2), U5.6 (CLK)
/RD+: J3.R3 (RD+), R34.1, U2.23 (RXP)
/RD-: J3.R6 (RD-), R35.1, U2.22 (RXN)
/RS485_A: D10.2 (K), J5.1, R15.1, R16.2, U13.6 (A)
/RS485_B: D10.1 (K), J5.3, R14.1, R15.2, U13.7 (B)
/RS485_DE: JP2.1 (A), U1.77 (PA15), U13.3 (DE)
/RS485_RX: U1.95 (PB8), U13.1 (RO)
/RS485_TX: U1.96 (PB9), U13.4 (DI)
/SDMMC_CLK: D6.3 (TVS2), J4.5 (CLK), R20.2, U1.80 (PC12)
/SDMMC_CMD: D6.1 (TVS1), J4.3 (CMD), R19.2, U1.83 (PD2)
/SDMMC_D0: D6.4 (TVS3), J4.7 (DAT0), R21.2, U1.65 (PC8)
/SDMMC_D1: J4.8 (DAT1), R22.2
/SDMMC_D2: J4.1 (DAT2), R12.2
/SDMMC_D3: J4.2 (CD/DAT3), R13.2
/SWCLK: J15.3, U1.76 (PA14), U8.6 (PA0)
/SWCLK_B: TP8.1, U8.20 (PA14)
/SWDIO: J15.1, U1.72 (PA13), U8.7 (PA1)
/SWDIO_B: TP7.1, U8.19 (PA13)
/TD+: J3.R1 (TD+), R32.1, U2.21 (TXP)
/TD-: J3.R2 (TD-), R33.1, U2.20 (TXN)
/U1_RX: J16.3, U1.69 (PA10), U8.8 (PA2)
/U1_TX: J16.1, U1.68 (PA9), U8.9 (PA3)
/USBD_D+: U1.71 (PA12), U9.4 (IO2)
/USBD_D-: U1.70 (PA11), U9.6 (IO1)
/USBH_D+: U1.54 (PB15), U10.4 (IO2)
/USBH_D-: U1.53 (PB14), U10.6 (IO1)
/USB_SER_D+: U7.4 (IO2), U8.18 (PA10/PA12)
/USB_SER_D-: U7.6 (IO1), U8.17 (PA9/PA11)
/VBUS3: C42.1, J2.1, TP4.1, U10.5 (VBUS), U14.5 (VOUT)
/~BOOT: JP1.2, R2.2, U1.94 (BOOT0)
/~QSPI_CS: R23.2, U1.79 (PC11), U5.1 (*CS)
/~RESET: C2.1, J10.2, J15.4, R1.2, SW1.1, U1.14 (NRST), U8.10 (PA4)
/~RS485_RE: JP2.2 (B), R24.1, U13.2 (~RE)
GND: BT1.2 (-), C1.2, C2.2, C3.2, C5.2, C6.2, C7.2, C8.2, C9.2, C10.2, C11.2, C12.2, C13.2, C14.2, C15.2, C16.1, C17.2, C18.2, C19.1, C20.1, C21.1, C22.2, C23.2, C24.2, C25.2, C26.1, C27.1, C29.2, C30.2, C31.2, C32.2, C33.2, C34.1, C35.1, C36.1, C37.2, C38.2, C41.2, C42.2, C43.2, D1.3 (A), D3.2 (-), D6.2 (COM), D6.5 (COM), D10.3 (A), H1.1, H2.1, H3.1, H4.1, J1.4 (GND), J1.5 (Shield), J2.4, J2.SH, J3.13 (SHIELD), J3.R8 (GND), J4.6 (VSS), J4.10 (GND_1), J4.11 (GND_2), J4.12 (GND_3), J4.13 (GND_4), J5.2, J5.5, J7.4 (GND), J7.5 (Shield), J9.1, J9.2, J9.23, J10.1, J10.3, J10.5, J10.7, J10.9, J10.11, J10.13, J10.15, J10.17, J10.19, J10.21, J10.23, J10.24, J13.2, J13.4, J13.6, J13.8, J13.10, J15.2, J16.2, J18.1, J18.3, J18.5, J18.7, J18.9, R2.1, R6.2, R7.1, R8.1, R9.1, R10.1, R16.1, R24.2, R26.1, R36.1, R37.1, SW1.2, SW2.1, U1.10 (VSS), U1.19 (VSSA), U1.26 (VSS), U1.49 (VSS), U1.74 (VSS), U1.99 (VSS), U2.25 (VSS), U3.1 (GND), U5.4 (GND), U6.4 (GND), U7.2 (GND), U8.15 (VSSA), U9.2 (GND), U10.2 (GND), U12.2 (GND), U13.5 (GND), U14.2 (GND)
unnamed: BT1.1 (+), D9.1 (K), D11.2 (A), R38.1
unnamed: C1.1, U1.48 (VCAP1)
unnamed: C3.1, U1.73 (VCAP2)
unnamed: C28.1, U6.6 (BST)
unnamed: C28.2, L1.1, U6.5 (SW)
unnamed: C29.1, D3.1 (+), TP5.1, U6.2 (EN), U6.3 (VIN)
unnamed: C32.1, U2.4 (XTAL2), Y3.1
unnamed: C33.1, U2.5 (XTAL1/CLKIN), Y3.2
unnamed: C43.1, R17.1, R18.1
unnamed: D7.1 (K), R9.2
unnamed: D8.1 (K), R10.2
unnamed: J3.L1 (LEDY_A), R36.2, U2.2 (LED2/~INT~/~PME~/~INTSEL~)
unnamed: J3.L2 (LEDY_K), R8.2
unnamed: J3.L3 (LEDG_K), R37.2
unnamed: J3.L4 (LEDG_A), U2.3 (LED1/~INT~/~PME~/REGOFF)
unnamed: R6.1, U2.24 (RBIAS)
unnamed: R26.2, U2.10 (RXER/PHYAD0)
unnamed: R5.1, R29.2, U2.14 (~INT~/REFCLKO)
VBUS1: D2.2 (A), J1.1 (VBUS), TP2.1, U9.5 (VBUS)
VBUS2: D5.2 (A), J7.1 (VBUS), TP3.1, U7.5 (VBUS)
VDC: C30.1, C31.1, D4.2 (A), L1.2, TP10.1, U6.1 (FB)
VDDETH: C16.2, C19.2, C20.2, C21.2, C35.2, FB1.2, J3.R4 (TCT), J3.R5 (RCT), R32.2, R33.2, R34.2, R35.2, U2.1 (VDD2A), U2.19 (VDD1A)
VDINA: D3.3 (~~), J8.1, J11.1, J11.3, J11.5, J11.7, J11.9
VDINB: D3.4 (~~), J8.2, J11.2, J11.4, J11.6, J11.8, J11.10

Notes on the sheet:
CPU
MEMORY
USER INTERFACE
PROTOBOARD
POWER
DEBUG & SERIAL
ETHERNET
USB Device
USB DEBUG
USB HOST
Populate JP4 when no battery is required
Populate D9, D11 BT1 and R38 when battery is required

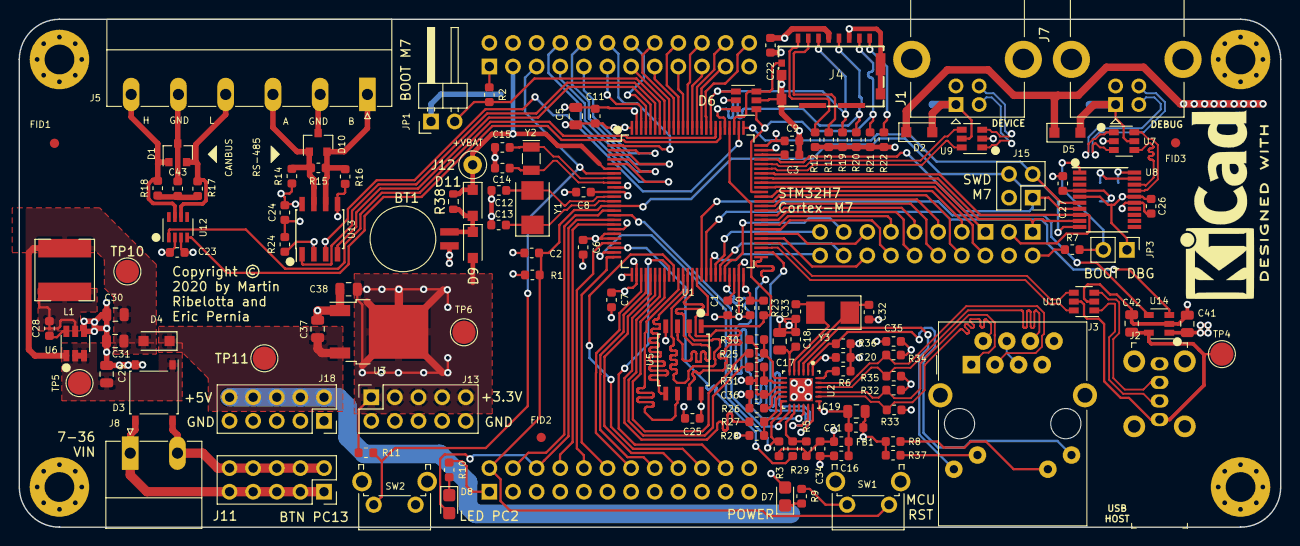
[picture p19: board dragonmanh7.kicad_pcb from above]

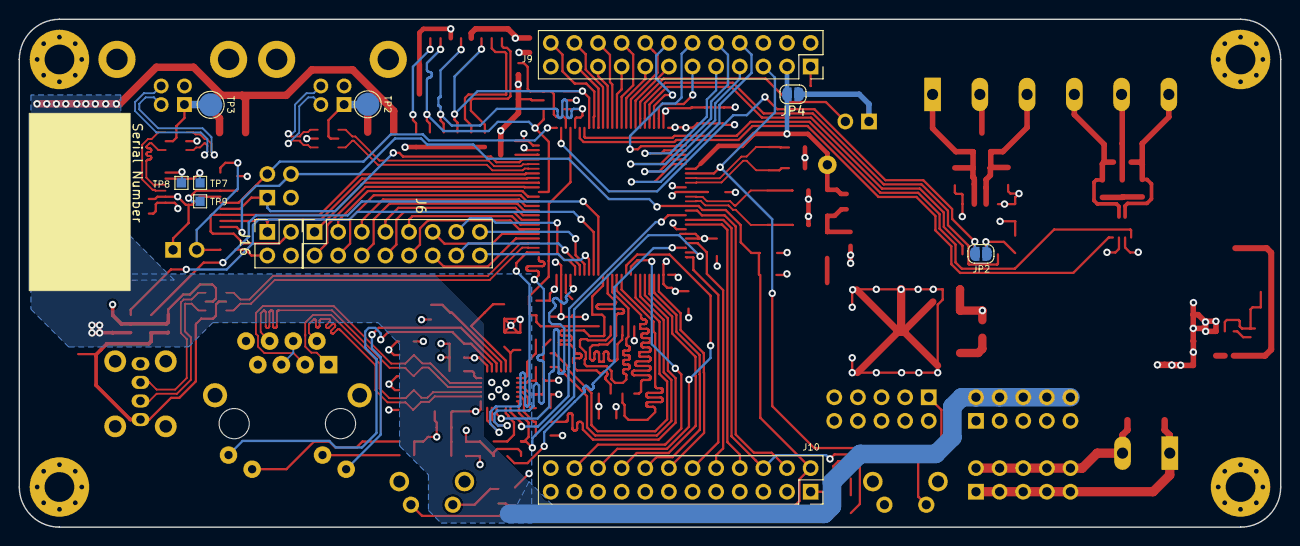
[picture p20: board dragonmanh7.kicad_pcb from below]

Board: 4 copper layers, 135.6 x 54.6 mm, 147 parts (11 on the bottom side), 141 nets.

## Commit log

2019-02-25 Final aproach with no can/485 isolation
    [trololo.kicad_pcb, trololo.sch]
2019-02-26 First isolation aproach
    [trololo.kicad_pcb, trololo.sch]
2019-05-12 Unknown changes
    [trololo.csv, trololo.kicad_pcb, trololo.sch]
2019-05-18 More unprecie modifications
    The log messages on this git sucks
    [trololo.kicad_pcb, trololo.sch]
2019-05-18 Add battery pins
    [trololo.kicad_pcb, trololo.sch]
2019-05-21 Add logos and change reset button and user led position
    [trololo.kicad_pcb, trololo.sch]
2019-05-21 Add packages 3d and last minutes touchs
    [1050170001.stp, ARJC02-111006.STEP, DM3AT-SF-PEJ2M5.stp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]
2019-05-21 Add exported gerbers
    [trololo-B_Adhes.gbr, trololo-B_Cu.gbr, trololo-B_Mask.gbr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]
2019-05-24 Add patrocinator logo, silkscreen correctios and minor route changes
    [trololo-B_Adhes.gbr, trololo-B_Cu.gbr, trololo-B_Mask.gbr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]
2019-05-24 Rename stupid name of trololo to more super-cool name dragonmanh7
    [dragonmanh7-B_Adhes.gbr, dragonmanh7-B_Cu.gbr, dragonmanh7-B_Mask.gbr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]
2019-05-25 Change power and rs485/can connectors
    [dragonmanh7-B_Adhes.gbr, dragonmanh7-B_Cu.gbr, dragonmanh7-B_Mask.gbr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]
2019-05-25 Fix power connector Y-position
    [dragonmanh7-B_Adhes.gbr, dragonmanh7-B_Cu.gbr, dragonmanh7-B_Mask.gbr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]
2019-05-25 Update gerbers
    [dragonmanh7-B_Adhes.gbr, dragonmanh7-B_Cu.gbr, dragonmanh7-B_Mask.gbr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]
2019-05-26 Fix L1 footprint
    [dragonmanh7-B_Adhes.gbr, dragonmanh7-B_Cu.gbr, dragonmanh7-B_Mask.gbr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]
2019-05-26 update gerbers for production
    [dragonmanh7-B.Cu.gbr, dragonmanh7-B.Mask.gbr, dragonmanh7-B.Paste.gbr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]
2019-05-28 Update images and README
    [dragonmanh7.kicad_pcb, dragonmanh7.sch]
2019-06-06 Minimal changes for production based on prototipe pitfalls
    - Change bootloader jumper polarity
    - More spaces in some capacitores
    - Add SWD-M7 connector in path to debugger mcu
    [dragonmanh7.kicad_pcb, dragonmanh7.sch]
2019-06-06 Remove unnecesary overlaps
    [dragonmanh7.kicad_pcb]
2019-06-19 Improve isolated area
    [dragonmanh7.csv, dragonmanh7.kicad_pcb, dragonmanh7.sch]
2019-06-20 Add usb host power controller
    [73725-0110blfc.stp, CUI_UJ2-BH-1-TH.step, dragonmanh7.kicad_pcb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]
2019-06-28 Change USB connectors to more hardness versions:
    - OTG1 to USB-B
    - DAP to USB-B
    - OTG2 to USB-A horizontal rigth angle
    - Move leds and buttons to bottom side
    - Align up and bottom headers
    - Add HOST power control on OTG2
    [dragonmanh7.kicad_pcb, dragonmanh7.sch, stm32h750-lqfp100-pinout.csv]
2019-06-29 Move gpio near gpio button and reubicate power led, update documentation
    [dragonmanh7.kicad_pcb]
2019-07-01 Fix gnd plane beside RJ45
    [dragonmanh7.kicad_pcb, dragonmanh7.sch]
2019-07-01 Reroute the power plane above RJ45 to prevent coupling
    [dragonmanh7.kicad_pcb]
2019-07-01 Improve ethernet connections (impedance matching TODO)
    [dragonmanh7.kicad_pcb]
2019-07-01 Impreove some traces
    [dragonmanh7.kicad_pcb]
2019-07-01 Remove rescue library from schematic
    [dragonmanh7.sch]
2019-07-01 Clear schematic library table and minor pcb footprint capacitor reorganization
    [dragonmanh7.kicad_pcb, dragonmanh7.sch]
2019-07-01 Improve reset tracesu
    [dragonmanh7.kicad_pcb]
2019-07-01 Add rs485/CANBUS optional termination footprints
    [dragonmanh7.kicad_pcb, dragonmanh7.sch]
2019-07-01 Minor changes in some traces
    [dragonmanh7.kicad_pcb]
2019-07-07 Revamp to non-isolated only
    [dragonmanh7.kicad_pcb, dragonmanh7.sch]
2019-08-25 Gerbers and clean information
    [dragonmanh7-B.Cu.gbr, dragonmanh7-B.Mask.gbr, dragonmanh7-B.Paste.gbr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]
2019-09-20 NonISO: Pullup in SDIO
    [dragonmanh7.kicad_pcb, dragonmanh7.sch]
2019-09-28 Change led resistor from 220R to 1K
    [dragonmanh7.kicad_pcb, dragonmanh7.sch]
2019-11-22 Tune track length for QSPI, ETH and SDMMC
    [dragonmanh7.kicad_pcb]
2019-12-01 Improve RS485 DE/nRE with jumper
    [dragonmanh7.kicad_pcb, dragonmanh7.sch]
2019-12-01 Fix interface schematic align and distriburtion
    [dragonmanh7.kicad_pcb, dragonmanh7.sch]
2019-12-01 Remove old logo and put kicad logo
    [dragonmanh7.kicad_pcb, dragonmanh7.sch]
2019-12-01 Add fidutial for automatic mounting
    [dragonmanh7.kicad_pcb, dragonmanh7.sch]
2019-12-08 Improve oscilator ground
    [dragonmanh7.kicad_pcb]
2020-01-12 Add voltage testpoints
    [dragonmanh7.kicad_pcb, dragonmanh7.sch]
2020-10-07 Change PHY to LAN8742 and change power scheme to improve 5V handling
    [Microchip_-_LAN8742A-CZ-TR.step, USB_C_Receptacle_Palconn_UTC16-G.step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]
2020-11-05 Improve schematic and PCB
    [dragonmanh7.kicad_pcb, dragonmanh7.sch]
2020-11-06 Change uSD card connector by Molex 1051620001
    [dragonmanh7.kicad_pcb, dragonmanh7.sch]
2020-11-06 Change usb-c to old usb-b connectors, move uSD to outter
    [105162-0001.step, dragonmanh7.kicad_pcb, dragonmanh7.sch]
2020-11-06 Rearrange logos and vias
    [dragonmanh7.kicad_pcb]
2020-11-06 Point of save
    [dragonmanh7.kicad_pcb]
2020-11-06 Move rigth side expansion to center
    [dragonmanh7.kicad_pcb]
2020-11-06 Saved point
    [dragonmanh7.kicad_pcb, dragonmanh7.sch]
2020-11-10 Add ESD filters to uSD connector, improve routing
    [dragonmanh7.kicad_pcb, dragonmanh7.sch]
2020-11-25 Minor changes, add uSD DET on PC10
    [dragonmanh7.kicad_pcb, dragonmanh7.sch]
2020-11-25 ETH and usb skew near of unmatched area
    [dragonmanh7.kicad_pcb]
2021-11-01 Point of restoration
    [dragonmanh7.kicad_pcb, dragonmanh7.sch]

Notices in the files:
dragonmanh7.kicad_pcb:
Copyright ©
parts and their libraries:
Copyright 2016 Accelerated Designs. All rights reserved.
